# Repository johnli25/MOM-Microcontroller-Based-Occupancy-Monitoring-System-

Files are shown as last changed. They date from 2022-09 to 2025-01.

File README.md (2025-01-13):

# Microcontroller-based Occupancy Monitoring (MOM)

### *Won ECE Senior Design Runner-Up Award* (Fall 2022)

## Authors and Acknowledgements
ECE 445 FA2022 Team 7:
- Franklin Moy
- Vish Gopal Sekar
- John Li
- TA: Hanyin Shao

## About
The goal of this project is to create a web app to allow users to determine how occupied popular study locations are.

## Repository Structure
- [**boards**](boards)
  - Contains KiCad project files for the hardware schematics and PCB layouts.
- [**code**](code)
  - Contains all software created for the project, including those used for RV processes and production code.
- [**models**](models)
  - Contains all custom symbols, footprints, and 3D models used for the hardware and enclosure design.
- [**notebooks**](notebooks)
  - Contains all individual lab notebooks.
 
## Paper/Report
[https://github.com/johnli25/MOM/blob/4fe8f952a4ed27d478e640dd72d3c75059fbbd7b/MOM%20Paper.pdf
](https://github.com/johnli25/MOM/blob/main/MOM%20Paper.pdf)
## The web app/dashboard


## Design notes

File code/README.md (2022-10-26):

# Arduino Code
This folder contains Arduino code for the ESP32-S3 microcontroller. This includes all code used for testing, verification, and project code.
## Setting up the Arduino IDE
- Install the Arduino IDE [from the Arduino website](https://www.arduino.cc/en/software).
- If the `hardware/espressif/esp32` folder is empty, run the below command:
  - `git submodule update --init --recursive`
- Run `get.exe` in the `hardware/espressif/esp32` folder.
- Plug in the board, open the Arduino IDE, and open the IDE preferences (from the topbar: `File->Preferences`).
- Change the Sketchbook location to this folder.
- Copy and paste the below line to the `Additional boards manager URLs`:
  - `https://arduino.esp8266.com/stable/package_esp8266com_index.json,https://dl.espressif.com/dl/package_esp32_index.json`
- Restart the IDE. You should now be able to communicate with the board.
- NOTE: If the IDE throws an error saying it couldn't get the FQDN, you will need to select the board from the topbar: `Tools->Port`

## MAC Address Filtering
In addition, we have a list of MAC address prefixes (also known as Organizationally Unique Identifiers, or OUIs) that belong to Aruba Networks, the company who manufactures the access points used for UIUC networks, and other devices which we believe are not student devices. We use this list to ignore MAC addresses that are a part of the building and improve accuracy of our readings. To get this list, we used the [https://maclookup.app](https://maclookup.app) database, which is derived from the official IEEE database of OUIs [here](https://standards-oui.ieee.org/oui/oui.csv), and put it in this repo [here](MOM/mac-vendors-export-2022-10-25.csv). The repo's snapshot of the database is up to date as of 2022-10-25. 

The list of OUIs can be scraped using the Python3 script [get_ouis.py](MOM/oui_lists/get_ouis.py). The script is used to find all OUIs of a specified company. The script has an argument of the company to find OUIs for. It is case insensitive as it will force all names to lowercase. An example usage is `python3 get_ouis.py aruba` to search for Aruba in the database. It will then output 2 files, one where it directly lists the OUIs in formatted hexadecimal form (`<COMPANY_NAME>-ouis.txt`), and one where the OUI is converted to unsigned integers (`<COMPANY_NAME>-ouis-uints.txt`).

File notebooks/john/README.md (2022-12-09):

# John's Lab Notebook
## Table of Contents
---
- [2022-09-13: Meeting Notes](README.md#2022-09-13-meeting-notes)
- [2022-09-14: Hardware Components Research](README.md#2022-09-14-Hardware-Components-research)
- [2022-09-16: Meeting with Jack Blevins](README.md#2022-09-14-Meeting-With-Jack-Kilby)
- [2022-09-20: Meeting-With-TA](README.md#2022-09-20-Meeting-With-TA)
- [2022-09-25: Finished-First-Draft-Of-Design-Doc](README.md#2022-09-25-Finished-First-Draft-Of-Design-Doc)
- [2022-10-04: Design-Document-review-and-presentation](README.md#2022-09-25-Design-Document-review-and-presentation)
- [2022-10-07: Finalizing-and-Ordering-Parts](README.md#2022-10-07-Finalizing-and-Ordering-Parts)
- [2022-10-18: More Findings about our Project](README.md#2022-10-18-More-Findings-about-our-Project)
- [2022-10-25: Implementation details + Assigning locker](README.md#2022-10-25-Implementation-details-and-Assigning-locker)
- [2022-11-04: Developing the Front End of the Web App](README.md#2022-11-04-Developing-the-Front-End-of-the-Web App)
- [2022-11-15: Mock Demo](README.md#2022-11-15-Mock-Demo)
- [2022-11-24: Thanksgiving Break](README.md#2022-11-24-Happy-Thanksgiving!)
- [2022-11-28: Finishing project for the final demo](README.md#2022-11-28-Finishing-project-for-the-final-demo!)
- [2022-12-4: Preparing-for-final-presentation](README.md#2022-12-4-Preparing-for-final-presentation)
- [2022-12-6: Final-presentation](README.md#2022-12-4-Final-presentation)

## 2022-09-13: Meeting Notes
Discussed with TA regarding our project proposal and our system and subsystem designs. Some things and suggestions to take note of:
- Add subcomponents for the cloud server for block diagram.
- Label necessary voltages at each power line for block diagram.
- Expand high-level requirement involving power to include 24-hour availability while the board is plugged in.
- Don't bother making your own Wi-Fi module; just buy one since budget is $150.

## 2022-09-14: Hardware Components Research
Since we have a limited $150 budget, all of our purchases will most likely be limited to Amazon, Digikey, and Mouser. Parts we are leaning toward using:

**Control Unit and Radio Scanner Suite**
  - [ESP32-S3-MINI-1](https://www.espressif.com/sites/default/files/documentation/esp32-s3-wroom-2_datasheet_en.pdf)
- This ESP32 is versatile, not super expensive, offers various functionalities, and is used in many IoT projects, both hobbyist and professional.
- Furthermore, this microcontroller has been proven to be compatible with AWS. 
- Currently, we aren't planning on integrating the 5 GHz frequency into the Radio Scanner Suite due to time constraints. The primary issue is that if we were to also scan 5 GHz, we would need to purchase a separate Wi-Fi module and write the drivers for it, which would take too much time and effort to integrate. So we plan on settling for 2.4 GHz frequency for our Wi-Fi module for now
- [USB-to-UART Bridge](http://esp32.net/usb-uart/): We need to make use of this bridge and attach it to our ESP-32. 

**Power Supply**
- LiPo battery: safe, effective, efficient, and cheap. Moreover, the "ease and form factor" of LiPo batteries are a plus.
- [AP2112 Voltage Regulator](https://www.digikey.com/en/products/detail/diodes-incorporated/AP2112M-3-3TRG1/5305555) (3.3V): The ESP32 series of SoCs all use 3.3 volts as their operating voltage. Since all USB types generally operating at or above 5 volts, we need to drop the voltage down. 3.3 V is a very common voltage for these sort of scenarios
- [MCP73831T Battery Charge Controller](https://www.digikey.com/en/products/detail/microchip-technology/MCP73831T-2DCI-OT/1979804): mainly used to prevent overcharging

## 2022-09-16: Meeting With Jack Blevins
We met with Jack Blevins, a UIUC alum whom has earned one of the first EECS degrees
back in 1970 and has a 50+-year track record spanning all kinds of
projects in industry (recommended to use by Professor Lumetta), and will essentially serve as another, "informal" mentor for our 445 project. Our team gave an overview of our project and followed up with some questions and comments from Jack:

- Jack essentially solidified our design decision from earlier and agreed that trying to implement and incorporate 5 GHz frequency into our Wi-Fi module would be too impractical. 
- For the Web programming side of things, we discussed which applications, languages, databases, etc. we were going to utilize. Since we established that we would be using AWS for our server side of things, we were leaning toward programming in Python and using a NoSQL Amazon database like DynamoDB. We were also open to using SQL or MongoDB from our discussions.
- Exchanged contact information so we can contact Jack whenever if we had any technical queries regarding our project.

## 2022-09-20: Meeting-With-TA

TA also sent back feedback for our project proposal. Some suggestions + improvements for our it are:

- Add range (+/- 1 minute) to occupancy updating time
- Update visual aid to add a few more explicit labels ("Occupancy data", etc.)
- Change "AWS IoT" in block diagram to "AWS server"
- More comments can be found on project proposal document that TA sent back to us 

We also discussed design document details. For example, creating a system/subsystem requirement | verification table. 

## 2022-09-25: Finished-First-Draft-Of-Design-Doc

- Finished first draft of Design Doc
- Main work we did was circuit schematics and requirements | verifications table for all the system & subsystem requirements

## 2022-10-04: Design-Document-review-and-presentation

- Prior to the Design document review on Monday (10/3/2022), our team made a couple revisions to some of the requirements and verifications, a block diagram, and the visual aid
- Design document presentation on Tuesday (10/4/2022) went well! Lots of great and constructive feedback from TAs, Professor Fliflet, and student peer reviews
- Judging from the feedback, the biggest functionality/implementation challenge we will most likely face is accurately estimating the Wi-Fi and Bluetooth signal strength/RSSI values while accurately pruning out "extra" or multiple signals and connected devices belonging to a single person.

## 2022-10-07: Finalizing-and-Ordering-Parts

- Our team finished finalizing and ordering all the necessary components for our project. Now we are just waiting for everything to arrive.

## 2022-10-18: More Findings about our Project 

- Our team finished finalizing and ordering all the necessary components for our project (PCB, etc.). Now we are just waiting for everything to arrive.

## 2022-10-25: Implementation details and Assigning locker

- We started writing the hardware arduino code for our project (Franklin started this) and cloud/AWS side of our project (Vish and I started looking and writing implementations for this)
- We also got a locker assigned to us, but it currently does not work.

## 2022-11-04: Developing-the-Front-End-of-the-Web-App

- The past couple works, I've been in charge of developing the front end side of the web app. 
- I used the Flask Python module to both design the front end and set up the pertinent connections and endpoints to our backend DynamoDB.
- I followed a Bootstrap + Jinja template for our front end design. The advantages for these web templates are 1) relatively simple learning curve with ample guides online 2) reactive/responsive 3) Provides a variety of designs, colors, graphs, charts, etc.
- The front end design is written in several HTML files so far: 'index.html' and 'pie-siebel.html'

## 2022-11-15: Mock-Demo
- Our group just performed a mock demo, and it went pretty well in my opinion. TAs said the demo went smoothly and we covered many of the requirements and verifications. We also received some very constructive feedback on what we need to address.
- Overall as a group, we need to run more tests on probing the number of devices/people in a closed room. Afterward, we will, together as a group, add more functionalities to ensure our occupancy probing and identifying algorithms and microcontroller sensor data collections are more smooth and consistent in both accuracy and latency
- On the web app side, I have to slightly update 1) the DynamoDB database structure/organizationd and 2) web app functionality in order to pull the most recent data from each room since we made a slight modification/optimization in that regard.
- This is optional but highly recommend. Change the front end design so there's one "home page" which lists all the rooms available on the web app. Then you can "click" on each room in order to navigate to that room and its occupancy metrics. 
- Also, if I have more time, prettify the web app by adding some more reactive widgets/features and colors. This part shouldn't be too hard

## 2022-11-24: Happy-Thanksgiving!
- Grind the points mentioned above and the rest of the MOM project over Thanksgiving break. Halfway-mostly done with the listed points in the entry above. Be ready for the real demo
- Happy Thanksgiving!

## 2022-11-28: Finishing-project-for-the-final-demo
- Finished all the technical/implementation aspects of the project --> ready to demo
- Web application is up, running, and deployed properly, DynamoDB is finished and presents and organizes data in a clean manner, and MOM device successfully reads WiFi signals and uploads to the AWS cloud successfully.
- Prep for demo by reviewing what Franklin, Vish, and I will be presenting which aspects of the project

## 2022-11-29: Demo
- Demo went great! TAs, peer reviewers, and professor liked our project!

## 2022-12-4: Preparing-for-final-presentation
- Prepared slides presentation and what Franklin, Vish, and I will be saying at the presentation
- Try on suits
- Prepared for our final presentation by doing mock presentation 
- also created a video the other day demonstrating our project/MOM device in action

## 2022-12-6: Final-presentation
- Final presentation went great!
- Some intriguing questions by the peer reviewers-if we had the time, their questions/suggestion are 100% worth considering!
- Done with project! Had a lot of fun working on it with my team. Lots of onerous, hard work and very stressful at times throughout the semester, but we got through it!

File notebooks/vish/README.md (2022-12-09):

# Vish's Lab Notebook

## Table of Contents

- [9/13/22: First Meeting with TA](README.md#9/13/22:-First-Meeting-with-TA)
- [9/16/22: Meeting with Jack Blevins](README.md#9/16/22:-Meeting-with-Jack-Blevins)
- [9/17/22: Identifying signals from only phones](README.md#9/17/22:-Identifying-signals-from-only-phones)
- [9/20/22: Second Meeting with TA](README.md#9/20/22:-Second-Meeting-with-TA)
- [9/26/22: Design Document Draft Review with TA and Professor](README.md#9/26/22:-Design-Document-Draft-Review-with-TA-and-Professor)
- [10/4/22: Design Document Presentation](README.md#10/4/22:-Design-Document-Presentation)
- [10/16/22: Development Board Testing](README.md#10/16/22:-Development-Board-Testing)
- [10/24/22: Parts and waiting on PCB](README.md#10/24/22:-Parts-and-waiting-on-PCB)
- [10/31/22: AWS pipeline](README.md#10/31/22:-AWS-pipeline)
- [11/5/22: IoT rule and DynamoDB](README.md#11/5/22:-IoT-rule-and-DynamoDB)
- [11/10/22: Flask Web App](README.md#11/10/22:-Flask-Web-App)
- [11/16/22: Elastic Beanstalk](README.md#11/16/22:-Elastic-Beanstalk)
- [11/27/22: Future Work and Improvements](README.md#11/27/22:-Future-Work-and-Improvements)
- [12/2/22: Post Demo and Preparations for Final Presentation](README.md#12/2/22:-Post-Demo-and-Preparations-for-Final-Presentation)

## 9/13/22: First Meeting with TA
In our first meeting with our TA, we made some introductions and gave her our pitch for the project proposal. Our TA said she did a similar project during her time as an undergraduate in ECE 445, but they used a very different approach with ultrasonic sensors instead. She gave us some advice on our project such as just purchasing a Wi-Fi module instead of trying to build one ourselves.

## 9/16/22: Meeting with Jack Blevins
Jack is an alum from the ECE Department and took some particular interest into our project as he thought it was very interesting. We met with him and gave our pitch for the project as well. He was definitely very invested in our project and gave some thoughtful feedback. He gave us an interesting scenario where the microcontrollers would be placed in neighboring rooms. He told us to find a work-around to account for the fact that the signals from one room could be actually reaching the microcontroller in the other room and vice-versa. This would give an inaccurate count of the number of people in the room as the signals would be counted twice.

## 9/17/22: Identifying signals from only phones
We were initially planning to capture signals from all devices emitting Bluetooth and Wi-Fi signals. However, I thought a more accurate count of the number of people in a room might be just identifying the signals from mobile phones instead. Since most people carry only one phone this would be a lot more accurate. I found a recent [paper](https://cseweb.ucsd.edu/~schulman/docs/oakland22-bletracking.pdf) on this topic where researchers talk about identifying whether the device is a mobile phone from the Bluetooth signal that it is emitting. Here is an [article](https://threatpost.com/bluetooth-signals-track-smartphones/179937/) summarizing this as well. Phones transmit a signal called Bluetooth beacons with an average rate of 500 beacons per minute. If our microcontrollers can somehow identify and isolate the signals that are giving about 500 beacons per minute, then we would be able to identify that the device is a phone. This method, however, might come with its own ethical considerations as it is actively trying to fingerprint and track the device as a phone.

## 9/20/22: Second Meeting with TA
The TA gave her feedback on our project proposal and things to look into for our upcoming design document submission. She told us to update our block diagram as some of the lines connecting to the cloud were confusing, since that's mostly used to indicate physical things. She also mentioned to update our visual aid with more specific labels.

## 9/26/22: Design Document Draft Review with TA and Professor
The Professor gave us some very helpful advice on revising our design doc. Some of the comments he gave:
- Be more specific with the RV table. Should be more low-level as well.
- Don't have random numbers in the requirements. There should be a clear reasoning behind the figures that we are coming up with. 

## 10/4/22: Design Document Presentation
We had our design document presentation yesterday and although we did pretty well, there were a few things that the professor and other peer reviewers brought up. In order to get within our 85% estimation for accuracy that we had in our high-level requirement, we are going to have to calibrate our RSSI value when we start prototyping with our MOM board. This value boundary may change depending on the size of the room/sector where we are testing as well, so we would have to do multiple iterations of it to find out what works to meet our accuracy requirement. During our meeting today there was also a good discussion we had about placement of the devices in a room. For example, what if someone on a floor above the room placed their phone on the ground, while the MOM board was attached on the ceiling of the room below. Arguably, the RSSI value from that device would be higher due to its proximity. Another case might be when a phone is charging from a wall outlet from a shared wall with the room where the MOM board is affixed to. Once again, the MOM board might be picking up signals from that phone, thinking it's also a part of the room. There's a lot of nuances like these cases that we have to do trial-and-error experiments to find an optimal RSSI value to calibrate our MOM boards to looks out for.

## 10/16/22: Development Board Testing
After we received our ESP32 Development Board we started working on figuring out how to pick up probe requests. One of the issues that we found while running our tests was that Apple devices were randomizing their MAC addresses. While all Apple devices did this on default, it was also possible to randomize the hardware addresses for devices running Windows. This would be a problem for our MOM device design, because it would count a probe request coming from a different MAC address every time as a different device, when in fact it might just be the same device sending probe requests with a randomized hardware address every time.

## 10/24/22: Parts and waiting on PCB
We finished ordering all our parts, however, we are still just waiting on our PCB to be delivered. Meanwhile, we are continuing test on the Development Board.

## 10/31/22: AWS pipeline
This week, I spent the bulk of my time refining the AWS Cloud pipeline and how that is going to fit in with the overall scope of the project. AWS has a service called IoT Core that lets you connect billions of IoT devices and route trillions of messages to AWS services without managing infrastructure. When these IoT devices publish messages, they are transmitted and received using the MQTT protocol which minimizes the code footprint on the device and reduces network bandwidth requirements. AWS IoT core is then able to process these messages, communicate with other IoT devices and interact with other AWS services as well. So far, I have gotten the ESP-32 to send MQTT messages to the AWS IoT Core and then it displays it there.

## 11/5/22: IoT rule and DynamoDB
After the MQTT data is saved in the IoT Core we need to save that data in a database, so we can pull it to the web app later. For the database to save to I chose DynamoDB because it is a fully managed, serverless, key-value NoSQL database designed to run high-performance applications at any scale. After messages are received to IoT Core from the ESP-32 using the MQTT protocol, data can be saved to DynamoDB. This can be achieved using the IoT Act Rule. It gives devices the ability to interact with other AWS micro services. Rules are analyzed and actions are performed based on the MQTT topic stream such as writing data received from a device to an Amazon DynamoDB database. 

## 11/10/22: Flask Web App
Now that all the data is saved in DynamoDB, the Flask Web app needs to pull this and display it on the application. I had some trouble with getting the access keys from AWS IAM initially, but after setting up the certificates correctly the Flask Web app was able to pull from my AWS account.

## 11/16/22: Elastic Beanstalk
Since our web application should be accessible from any device, we need a place to host it from that can be accessible easily. Elastic Beanstalk seemed like a good option because it automatically handles the deployment details of capacity provisioning, load balancing, automatic scaling, and web application health monitoring. When trying to initially host it there, we ran into some trouble of getting the dependencies to work in the virtual environment. However, after including a requirements.txt file and writing an appropriate config file, the deployment was successful.

## 11/27/22: Future Work and Improvements
Contrary to our initial inception of the project where we wanted to use both Bluetooth and Wi-Fi signals for occupancy monitoring, we could only implement it with Wi-Fi signals in the end. Implementing occupancy monitoring using Bluetooth proved to be a lot harder than what we expected. However, in the future given more time to work on the project we plan on using a weighted average between cumulative Bluetooth and Wi-Fi traffic to better capture how busy a specific room is. 

Another future improvement to our project could be to include a graph of the most popular times when a room is busy and usually open. This graph would go right below our occupancy pie chart on our web application. The graph would forecast when a room is most available based on historical occupancy data that we would have collected and stored in our database. Using this approach, we could get a rough estimate of the number of people for a given future time. To forecast future occupancy, we could also use more sophisticated models such as an LSTM (Long Short-Term Memory) model which is a type of recurrent neural network that has vast applications when given time series data as inputs. Here is an [article](https://machinelearningmastery.com/how-to-develop-lstm-models-for-time-series-forecasting/) summarizing this well. It can predict pretty accurately when given proper data points and trained appropriately.

## 12/2/22: Post Demo and Preparations for Final Presentation
Our demo went great earlier this week, and our MOM device was 100% accurate in estimating the number of occupants in the senior design lab when we were demonstrating it. We got great feedback from the professor and TAs. As we get near the end of the semester, we need to finish our last two major assignments: Final Presentation and Final Report. We each went over what we will be presenting and rehearsed our sections with a mock presentation, so it would be smooth during the actual one. Also started working on the Final Report since it is due Wednesday next week.

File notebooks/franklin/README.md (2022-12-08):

# Franklin's Lab Notebook
## Table of Contents
- [2022-09-13: Post-Meeting Notes](README.md#2022-09-13-post-meeting-notes)
- [2022-09-14: Parts Research](README.md#2022-09-14-parts-research)
- [2022-09-14: Quick note about our traffic monitoring method](README.md#2022-09-14-quick-note-about-our-traffic-monitoring-method)
- [2022-09-15: AWS Research](README.md#2022-09-15-aws-research)
- [2022-09-24: Full Bill of Materials for MOM Node Prototype 1](README.md#2022-09-24-full-bill-of-materials-for-mom-node-prototype-1)
- [2022-10-02: Calculations and Design Approaches for the Schematic](README.md#2022-10-02-calculations-and-design-approaches-for-the-schematic)
- [2022-10-11: Concerns that arose while doing early testing](README.md#2022-10-11-concerns-that-arose-while-doing-early-testing)
- [2022-10-21: Thinking about implementation](README.md#2022-10-21-thinking-about-implementation)
- [2022-10-26: Experimenting with Probe Requests](README.md#2022-10-26-experimenting-with-probe-requests)
- [2022-11-04: Integrating AWS IoT](README.md#2022-11-04-integrating-aws-iot)
- [2022-11-11: Device Enclosure Preparation with Machine Shop](README.md#2022-11-11-device-enclosure-preparation-with-machine-shop)
- [2022-11-17: Tinkering with the Occupancy Estimation Algorithm](README.md#2022-11-17-tinkering-with-the-occupancy-estimation-algorithm)
- [2022-11-25: Fall Break](README.md#2022-11-25-fall-break)
- [2022-12-02: The Occupancy Contribution/Probability Model](README.md#2022-12-02-the-occupancy-contributionprobability-model)

## 2022-09-13: Post-Meeting Notes 
We just talked with our mentor TA about our initial block diagram, high-level and subsystem requirements, and about some of the parts that we are planning on using for the project. She had some great suggestions for us that we think would benefit our project, especially since she had a very similar project when she took the course. \
Here's the list of suggestions that she mentioned:
- Add the subcomponents for the cloud server in the block diagram.
- Put required voltages at each power line in the block diagram.
- Expand the high-level requirement involving power to include 24-hour availability while the board is plugged in.
- Don't bother making your own Wi-Fi module; just buy one since the budget is $150.

## 2022-09-14: Hardware Parts Research
Now that we kind of have our project idea fleshed out, we need to create an initial list of parts to create our prototype. All research will be done with the fact that the budget can only be used on Amazon, Digi-Key, and Mouser. Below is a list of all parts and components, sorted into subsystems, I have researched that should be purchased from the aforementioned sites, along with my thought process behind picking those parts.
- **Control Unit and Radio Scanner Suite**
  - [ESP32-S3-MINI-1](https://www.espressif.com/sites/default/files/documentation/esp32-s3-mini-1_mini-1u_datasheet_en.pdf)
    - It's no question that the ESP32 family has a good track record with IoT projects. It's very inexpensive and it has a decently-sized community around it to provide support and answers should someone need it.
    - It's also approved and supported by AWS, which is a huge plus should we need help in the programming side of the project.
    - To make this easier for us to quickly build the prototype, we need an ESP32 SoC that has an integrated Bluetooth module as well as a Wi-Fi module to quickly integrate the ***Radio Scanner Suite***. This means we need to get an ESP32 with antennas.
    - As of right now, we aren't planning on integrating the 5 GHz frequency into the ***Radio Scanner Suite*** due to time constraints. The main issue is that if we were to also scan 5 GHz, we would need to purchase a separate Wi-Fi module and write the drivers for it, which would take too much time to integrate.
      - However, the ESP32 that we are getting has native USB support, so if we have the time to integrate the device drivers for the 5 GHz band, we would be able to do so.
      - On the bright side, Espressif is currently developing the ESP32-C5, which will have dual-band and Bluetooth LE capability. This would be the easiest upgrade to scan all Wi-Fi and Bluetooth frequencies, but the release date for this SoC is not currently known (as of 2022-09-14).
  - ~~[USB-to-UART Bridge](http://esp32.net/usb-uart/)~~
    - ~~We need a USB-to-UART bridge IC to actually program our ESP32. The link goes to a web page with a list of USB-to-UART ICs used in other ESP32 development boards, so we know picking one of those should work.~~
    - ~~We are also planning on powering the board through USB when it is plugged in.~~
    - The USB-to-UART Bridge is not necessary for the ESP32-S3 because it has native USB CDC and JTAG support.
      - I go over this in more detail in the notebook entry [2022-09-24: Full Bill of Materials for MOM Node Prototype 1](README.md#2022-09-24-full-bill-of-materials-for-mom-node-prototype-1).
- **Power Supply**
  - LiPo battery
    - 18650 batteries are probably the better choice over choosing a LiPo pack when it comes to the price-to-capacity ratio. However, the ease and form factor of LiPo batteries are more suitable for our design since it's easier to tuck and keep hidden away.
  - [AP2112 Voltage Regulator](https://www.digikey.com/en/products/detail/diodes-incorporated/AP2112M-3-3TRG1/5305555) (3.3V)
    - The ESP32 series of SoCs all use 3.3 volts as their operating voltage. Since all USB types generally operating at or above 5 volts, we need to drop the voltage down. The AP2112 is a tried and true voltage regulator for 3.3 volts, so we'll use it in our design, too.
  - [MCP73831T Battery Charge Controller](https://www.digikey.com/en/products/detail/microchip-technology/MCP73831T-2DCI-OT/1979804)
    - It's very important to keep the battery from overcharging. This battery charge controller appears to be very popular with other boards that are based on ESP32.

## 2022-09-14: Quick note about our traffic monitoring method
So when our team initially talked about this idea, we were certain that we would need to purchase a separate Wi-Fi module to scan both bands of the 802.11 spectrum (2.4 GHz and 5 GHz). However, after a bit of research, and because of a hardware limitation of the ESP32 platform (as of 2022-09-14), we found that only scanning the 2.4 GHz frequency may be sufficient. This is because most Wi-Fi devices send probe requests after a certain event or a certain amount of time, which is dependent on the operating system used by the probing device. These probe requests are sent on both the 2.4 GHz and 5 GHz bands, since not all Wi-Fi networks utilize the 5 GHz band. 

The discovery phase of a Wi-Fi connection can be broken down to the following steps:
1. Wi-Fi client sends a (periodic) probe request to its general viscinity.
2. All Wi-Fi access points (APs) that have read the probe request frame generate and send a probe response to the client (unless the AP is configured otherwise).
3. Wi-Fi client received the probe response from the responding APs to generate the list of available Wi-Fi connections.  
  
Here are some good references to take a look at to learn more:
- [What are Passive and Active Scanning? - Wi-Fi Alliance](https://www.wi-fi.org/knowledge-center/faq/what-are-passive-and-active-scanning)
- [802.11 MAC Series – Basics of MAC Architecture – Part 3 of 3 - CWNP](https://www.cwnp.com/802.11-mac-series-ndash-basics-mac-architecture-ndash-part-3/)
- [Oliveira et al. 2019](https://ieeexplore.ieee.org/stamp/stamp.jsp?arnumber=8747391)

## 2022-09-15: AWS Research
Here's an official AWS web page about how to use AWS for the connected home. This diagram outlines our potential flow with respect to how each device in our fleet will interact with AWS. [Link to diagram here](https://aws.amazon.com/iot/solutions/connected-home/).

## 2022-09-24: Full Bill of Materials for MOM Node Prototype 1
For me, this entire week was spent on finalizing the bill of materials for the first prototype of a MOM node. This list goes in-depth on all major ICs, receptacles, and connectors needed for each MOM node.
- [ESP32-S3-MINI-1-N8 SoC](https://www.digikey.com/en/products/detail/espressif-systems/ESP32-S3-MINI-1-N8/15295890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)
  - ESP32 is a powerful and popular family of SoCs that have microcontrollers, GPIO connectivity, and integrated Wi-Fi and Bluetooth transceivers. We picked the ESP32-S3 specifically because it does not require the use of a separate USB-to-UART bridge to communicate with it from a computer. This is because it contains a USB On-The-Go chip that also supports USB CDC and JTAG. [You can read more about it here](https://docs.espressif.com/projects/esp-idf/en/latest/esp32s3/get-started/establish-serial-connection.html).  
- [Molex USB 2.0 Type-C Receptacle](https://www.digikey.com/en/products/detail/molex/2137160001/13662558)
  - We plan on using USB for flashing software and for the power supply. Thus, we need a USB receptacle for the board.
- [AP2112 (3.3V) Linear Voltage Regulator](https://www.digikey.com/en/products/detail/diodes-incorporated/AP2112M-3-3TRG1/5305555)
  - The ESP32 has a normal operating voltage of 3.3V, and since both LiPo batteries and USB power supply higher voltages, we need to step it down using a voltage regulator. 
- [MCP73831-2ACI Battery Charge Controller](https://www.digikey.com/en/products/detail/microchip-technology/MCP73831T-2ACI-MC/7065590)
  - To ensure proper safety and health of the LiPo backup battery, we will use a battery charge controller. This battery charge controller is popular with other ESP32-based boards.
- [LC709204 Battery Fuel Gauge](https://www.digikey.com/en/products/detail/microchip-technology/MCP73831T-2ACI-MC/7065590)
  - We thought that it would be nice to receive a notification if a node is running on battery power so that we would know if a node's wall power supply needs to be checked out. This battery fuel gauge IC is easy to use and connects directly using I2C.
- [3.7V Li-Po Battery (JST-PH connector)](https://www.digikey.com/en/products/filter/batteries-rechargeable-secondary/91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)
  - This will act as a battery backup should a node's wall power be disconnected for whatever reason.
- [2-pin JST-PH Header](https://www.digikey.com/en/products/detail/jst-sales-america-inc/S2B-PH-K-S-LF-SN/926626)
  - This is a connector for the LiPo battery.
- [DMG3415U MOSFET](https://www.digikey.com/en/products/detail/diodes-incorporated/DMG3415UFY4Q-7/5970445)
  - This is the Diode-OR circuit that will decide whether the wall charger or the battery will power the node.  
- [NRVB540MFS Diode Rectifier](https://www.mouser.com/ProductDetail/onsemi/NRVB540MFST1G?qs=xGcJQ%252BnsJwtnjlj0htu6yg%3D%3D)
  - This diode rectifier is used to keep the incoming power as steady as possible so that other components receive steady power.

## 2022-10-02: Calculations and Design Approaches for the Schematic
- **USB Type-C** 
  - Our decision to use USB for our device stems from the fact that our microcontroller needs to connect to our laptops somehow so that we can program them. Since all modern laptops have USB ports, it would make sense to have a USB interface with the microcontroller so that we can just plug in a USB cable.
  - As we would like to "future-proof" our devices, we decided to go with a USB Type-C receptacle instead of a Micro USB (USB OTG) receptacle.
  - USB is a standard which provides a bus to power devices and transfer data, which makes it a perfect all-in-one solution.
  - MOM devices will never act as USB hosts, as they are simply going to be powered by a USB power supply or will just be programmed by a host computer, so they are (electrically) treated as a sink device on the Configuration Channel (CC) pins.
    - All sink devices will need to have their Configuration Channel pins connected to 5.1K Ohm resistors that are connected to ground.
    - USB Type-C Configuration Channel Requirements  
    - A more in-depth review of the electrical aspects of USB Type-C can be seen in [this document provided by STMicroelectronics](https://www.st.com/resource/en/technical_article/dm00496853-overview-of-usb-type-c-and-power-delivery-technologies-stmicroelectronics.pdf).
- **Battery Charging Circuit**
  - Since we would like to have our backup battery charge while the MOM device is plugged into wall power, we will have a battery charging circuit on the MOM device.
  - This battery charging circuit (part of the Power Supply subsystem) is made up of two ICs: an MCP73831 battery charge controller and a MAX17048G battery fuel gauge.
  - The MCP73831 is a popular battery management controller for Lithium-Polymer batteries. As such, we chose it as our battery charge controller.
    - Because we want to have each MOM device to last for at least one hour while on battery power, we calculated that the minimum battery capacity required to do so is at least 500mAh.
    - For Lithium-Polymer batteries, it is unsafe to charge it at a current that is higher than its capacity divided by one hour. For our battery, this means that we should not charge it using a current higher than 500mA.
    - The MCP73831 datasheet provides a simple formula (seen below) that we can use to set its charge rate by using a programming resistor at its "PROG" pin.
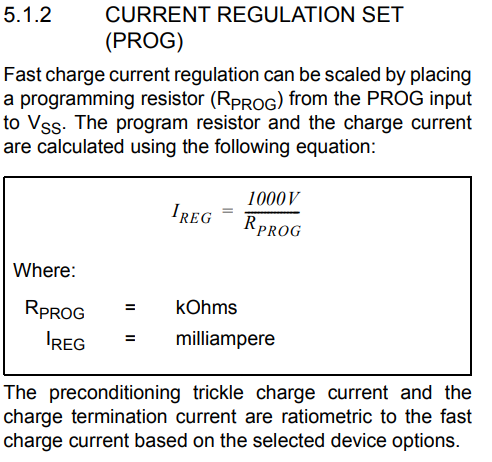
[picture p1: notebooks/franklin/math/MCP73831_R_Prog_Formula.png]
MCP73831 charge rate formula from its datasheet
    - 
    - From this formula, we can see that the resistance of the programming resistor required to set the current to no more than 500mA is ***2K Ohms***.
  - The MAX17048G is a battery fuel gauge that can calculate battery levels and communicate its findings over I2C. We plan on using this to display the battery level of each node so we can determine if there are any issues with the battery backup of that node.
    - Since we are going to just use it as a simple fuel gauge, we decided to use the typical application circuit shown below (which was also from the datasheet).
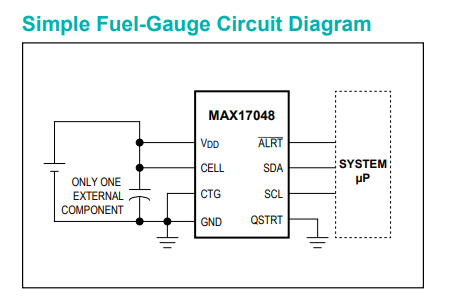
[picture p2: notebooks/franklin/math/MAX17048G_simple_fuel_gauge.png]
Simple MAX17048G fuel gauge circuit
    - 
- **Battery Backup Switchover**
  - After doing some research, I found that the most efficient circuit for a (relatively) seamless battery backup switchover circuit involves a P-channel MOSFET. By having the voltage from USB as the gate, and the voltage from the battery as the source/drain, you can easily decide which power source to draw from.
  - In this setup, when USB is powering the device, the voltage drop between the gate and source (Vgs) will be above the turn-on voltage range, so no power from the battery will go through. When USB is disconnected from the device, Vgs will be within the range of turn-on voltage range, allowing power from the battery to go through.
  - There is a Schottky diode used to protect the USB power line from battery power. A Schottky diode was chosen due to its low turn-on/forward voltage, and the specific model being used was chosen due to its combination of high reverse voltage blocking and low reverse current leakage.
- **Voltage Regulator**
  - The AP2112 is a commonly used voltage regulator in microcontroller platforms that use 3.3 volts, so we picked it because of that. 

## 2022-10-11: Concerns that arose while doing early testing
Our parts came in earlier this week and we were able to pick them up. Among the parts that we ordered is a development board that we plan to use to code our microcontroller program while we wait for PCB orders to be fulfilled. As we started developing, we found out about an issue that would force us into making certain algorithm design decisions. This issue is how a device is able to randomize its Wi-Fi MAC address. For example, every time an iOS device sends a probe request, it will randomize its MAC address for each request. This would make it very difficult to have the true count of devices using just basic MAC address storage/lookup. 

We're thinking that one way of mitigating this would be connecting to IllinoisNet instead of the IllinoisNet_Guest network so that we could truly monitor just IllinoisNet. This would cause each device to just be mapped to a single MAC address since the MAC address cannot be changed during a connection. Since IllinoisNet requires a certificate, we could do something similar to how [someone at UMich connected their ESP32 to their university's network](https://www.youtube.com/watch?v=bABHeMea-P0).

Fortunately, one of the references in our RFA/design document proposes another way of mitigating this. You can read the proposed method in the [research publication on IEEE](https://ieeexplore.ieee.org/stamp/stamp.jsp?tp=&arnumber=8747391).

## 2022-10-21: Thinking about implementation
So while we're waiting for our PCB to come in, we've been developing using the development board that we ordered. So far, we have had a bit of success with the current code that we have. Now, we're trying to look for ways to optimize the counting algorithm and make it as accurate as we can. This involves a bit more testing and some more math. We've also started researching how to implment the IoT Cloud subsystem on AWS and how to connect the development board to it. 

## 2022-10-26: Experimenting with Probe Requests
I spent a couple days this week trying to tune the parameters for Wi-Fi scanning. However, one of the problems that I found while I was experimenting was with respect to the frequency that devices send probe requests while already connected to a network. When a device sends a probe while already connected to a network, it sends significantly fewer probe requests than if it were not connected. 

One of my experiments this week involved finding the time intervals in which different computer operating systems send probe requests while already connected to a network. I put a MOM node next to the devices I was testing and let it collect data over a period of one hour. These devices consisted of my laptop running Windows 10/11, a smartphone running Android, a smartphone running iOS, and one of my roommate's laptops running macOS. My roommate and I were actively using our respective laptops, while both smartphones were left in a locked state.

During this one hour interval, I found that devices running Windows 10/11 send a probe request about every 10 minutes (which can be seen in the screenshots below). On one occasion, our MOM device caught traffic from the Windows device less than 2 minutes after its previous probe request, but this wouldn't have an effect on how we plan on measuring occupancy if this happened in the real world. 

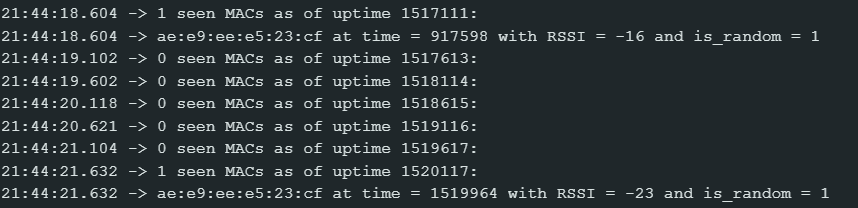
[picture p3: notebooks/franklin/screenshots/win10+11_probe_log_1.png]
Windows 10 Probe Request detection 1

Windows 10 Probe Request detection 2
Windows 10 Probe Request detection 3

We also found that the probe request interval for MacBooks running macOS is also about every 10 minutes. However, we found that iOS rarely sends probe requests when it is locked. This could be a double-edged sword. On one hand, it helps mitigate over-counting people if they have multiple Wi-Fi devices. On the other hand, if a person isn't using their laptop (if they are taking a break from studying, for example) we could be under-counting because the MOM node would not count the actively used smartphone. In the end, I'll still need to figure out if (and how) we can keep the occupancy measurement as close to ground truth as possible.

## 2022-11-04: Integrating AWS IoT
I spent the bulk of this week adding the integration with AWS IoT into the microcontroller codebase. To publish the occupancy data to the database for the web application to use, the microcontroller will use the MQTT protocol to send messages to the AWS IoT Core. The AWS IoT Core can then forward the MQTT message it receives from the MOM device to a database via a forwarding rule. The web application can read from the database to update the occupancy data on the web page. This follows the official AWS IoT Core flow diagram below.

Official AWS IoT flow diagram

Since there is only one Wi-Fi antenna on the ESP32-S3, it cannot be connected to the internet and scan for Wi-FI traffic simultaneously. To overcome this, I programmed the microcontroller to switch between the two modes. Depending on what part of the data collection flow the MOM node is currently on, it will set the Wi-Fi antenna to the corresponding mode. When it is scanning, the antenna is put into promiscuous mode. After a certain amount of time, promiscuous mode is turned off, and it starts to estimate the occupancy based on the scan data. After it does that, it will set the Wi-Fi antenna to station mode and connect to the internet and AWS. Once it publishes the data, it will disconnect from the internet and re-enable promiscuous mode to scan for probe requests again. See the flowchart and an example demo screenshot below.

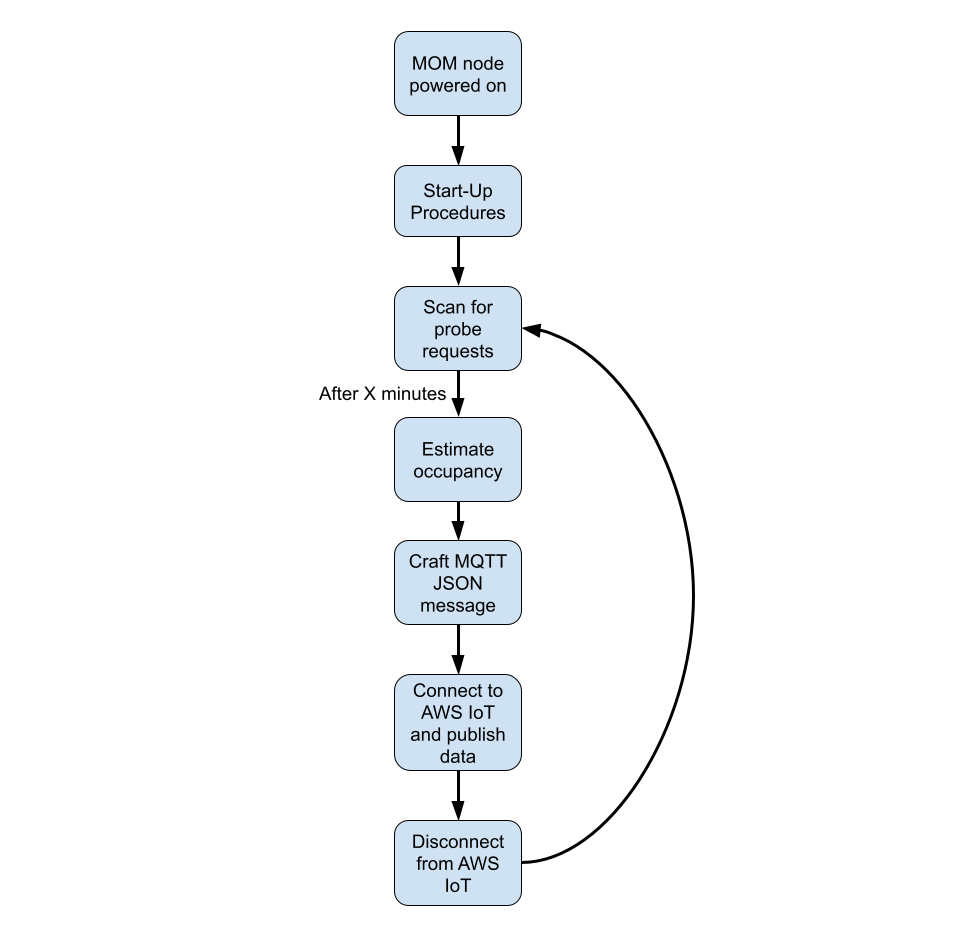
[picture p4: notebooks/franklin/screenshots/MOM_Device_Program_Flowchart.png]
MOM Device Flowchart


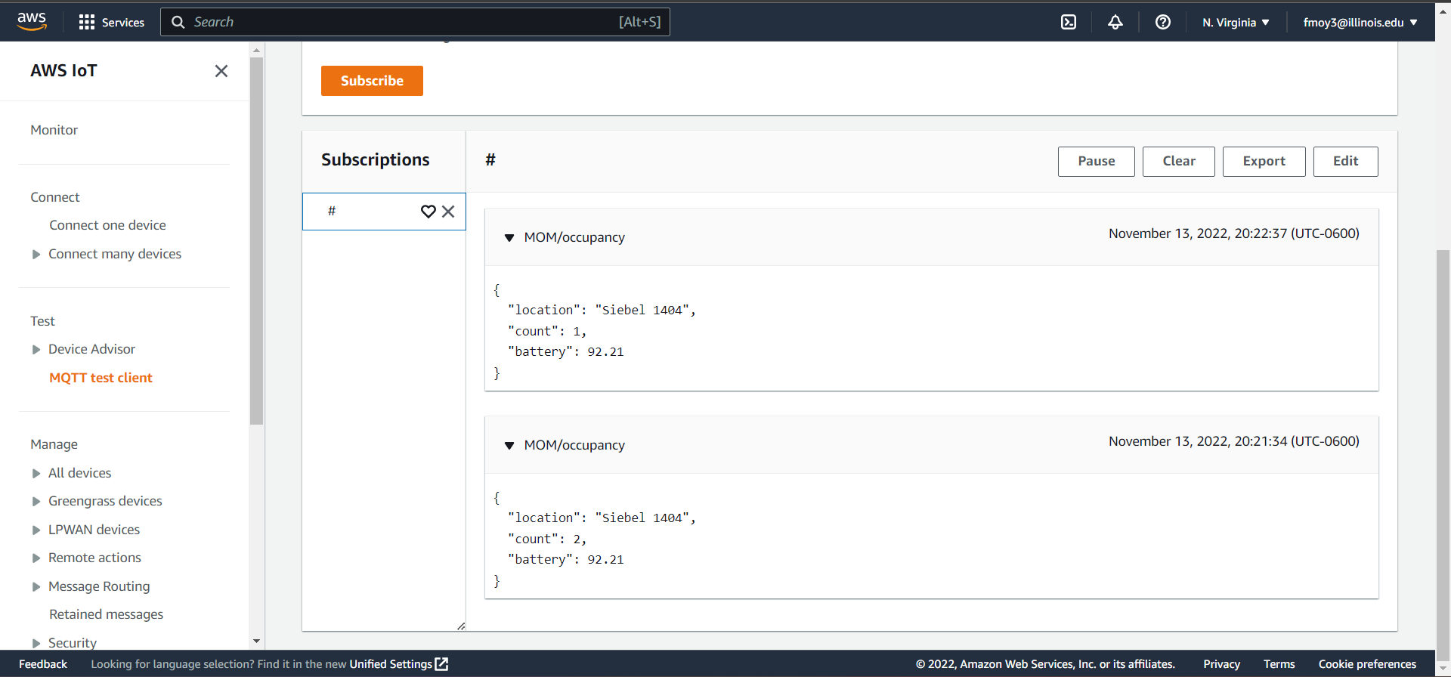
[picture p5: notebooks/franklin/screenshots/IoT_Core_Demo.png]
MOM IoT Core Demo


## 2022-11-11: Device Enclosure Preparation with Machine Shop
I spent this week with more attempts of fine tuning the occupancy estimation algorithm. Unfortunately, I couldn't get too much progress with this, even after reading some more research papers on the topic. The primary issue with referencing most of the research papers on the topic of occupancy detection through probe requests is the fact that the scenarios that apply to the research publications don't apply to the scenario in which we are deploying MOM. I briefly touch on this in [2022-10-26: Experimenting with Probe Requests](README.md#2022-10-26-experimenting-with-probe-requests), but to elaborate, the research publications target scenarios when the devices are not already connected to a network, such as on public transportation or while out and about. 

In these scenarios, client devices send probe requests much more frequently, allowing the researchers to use algorithms to map patterns to estimate occupancy. Since we plan on deploying MOM devices in places such as a public library, the devices will already be connected to a network like IllinoisNet. This makes it harder for us to keep tabs on these devices in real-time since they don't send probe requests often, if at all, while already connected to the internet. I am trying to come up with an algorithm of my own to estimate occupancy in our situation, which I will be continuing work on next week.

Meanwhile, I was also working with Gregg from the Machine Shop this week to build an enclosure for our MOM device. We found a plastic enclosure that suits the size of our PCB and backup battery. A plastic enclosure should not affect any the signal strength parameters that the algorithm uses since plastic is practically invisible to the 2.4GHz waves that we are using. Gregg and the others from the Machine Shop will drill holes in the plastic enclosure so that the MOM board can be mounted to the case. Also, a hole will be made on one side of the enclosure for the USB-C port on the board, allowing for easy connection with a USB-C cable to program and power the board while it is in the case.

## 2022-11-17: Tinkering with the Occupancy Estimation Algorithm
At this point, the physical MOM device is ready and is packaged in an enclosure. I've noticed that the enclosure slightly interferes with the RSSI tolerance ranges that the algorithm uses, but it shouldn't have too much of an impact. However, as I was adjusting these tolerances, I found that the current algorithm does not do a good job of trying to mitigate things such as counting people who are simply passing by and the MAC address randomization used for probing by mobile devices, both of which would cause overcounting. 

Another concern is that not every Windows machine will send periodic probe requests while already connected to the internet. For example, my Windows laptop is equipped with an Intel Wi-Fi controller. When I was testing an earlier version of the algorithm a couple of weeks ago, I found that my laptop sent probe requests with a period of about 10 minutes. However, one of my teammate's laptops has a Wi-Fi controller manufactured by a different company. As these Wi-Fi controllers are made by different companies, the software drivers for them are also developed differently. As such, they may not behave exactly the same, and this is what I saw with my teammate's laptop, as it didn't probe at all when already connected to the internet during a 30-minute testing period.

Because of this and the possible overcounting, I decided to rethink what exactly occupancy would mean in our project, since we won't be able to reliably map the occupancy to just the number of MAC addresses we see from probe requests at a given point in time. For now, the best metric/model I could think of involves traffic flow and how busy the area seems. As someone walks through a building, their smartphone's connection to the access point it was previously connected to becomes weaker and weaker. It is at this point when the smartphone sends a probe request to try and connect to an access point with a stronger signal. If we can capture this traffic flow and then try to map it to the number of people in an area, then we can estimate occupancy that way. We also need to consider signal strength relative to the MOM device to try to see if the traffic is within the room or just passing by.

## 2022-11-25: Fall Break
This week was Fall Break, and since I was more or less done with building the physical MOM device and developing the microcontroller code for it, I was only performing the final verifications and recording our results. All of the requirements for the subsystems I was in charge of have been verified, and so was the high-level requirement of the device running for at least one hour while on battery power. However, because of the scarcity of sent probe requests by devices already connected to the internet, the high-level requirement of estimating sector occupancy with at least 80% accuracy is becoming increasingly more difficult through just measuring probe requests. If we used a much more intrusive method, this would not be too difficult. However, ethical reasons deter the usage of these intrusive methods.

## 2022-12-02: The Occupancy Contribution/Probability Model
We noticed that after monitoring a space for a long time, the MOM device eventually reads an explosive increase in detected devices when no new people enter the room, which in turn increases the estimated occupancy. To mitigate this, we instead calculate occupancy based off of the probability that the detected device represents an entire person. With this new probability model, we try to take into account factors such as the number of devices per person, the dimensions of the environment where the device is deployed, and extraneous traffic from devices from other areas (such as other floors and other rooms). The probability primarily focuses on the signal strength and timestamps of each captured probe request, where the probability decays over time if the device has not been seen for a while since the previous timestamp. We also tried to implement a way to detect explosive increases in detected devices within a short period of time. While we were able to detect and mitigate these, the algorithm we use would ignore explosive increases if it actually happened. For example, if a class is starting in a classroom, and many students enter the room at the same time, the algorithm currently thinks that mitigation actions are required even though the increase is the ground truth.

In general, the mitigation would not really matter too much for the areas where we would be primarily deploying MOM devices, such as Grainger Library and the ECEB Atrium, since those are large, open spaces with lots of movementand traffic flow. When we tested this algorithm in the Senior Design Lab, we found that it works relatively well. It would be rare to see explosive increases in occupancy in a short period in those spaces. However, the shortcoming of this mitigation approach is losing the accuracy in smaller rooms. Given more time to fine-tune the mitigation algorithm, I believe that we would be able to find an optimal way to identify when mitigation actions should be taken based on these explosive increases.

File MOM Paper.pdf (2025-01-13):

# ECE 445

### Senior Design Laboratory Fall 2022 Final Report

# Microcontroller-based Occupancy Monitoring (MOM)

Team 7: Franklin Moy, Vish Gopal Sekar, John Li TA: Hanyin Shao
12/07/2022

## Abstract

Microcontroller-based Occupancy Monitoring (MOM) is a project which shows the current occupancy of a space to its users. The MOM device monitors Wi-Fi traffic density to estimate the number of people in a space in real-time. This estimation is presented on a web application for the public to use. By using the web application, users can know if a location is likely to have available seats without needing to physically visit the location. Using a custom algorithm with finely-tuned parameters, MOM is able to estimate the number of people in a large, enclosed space with at least 80% accuracy and update the web application every five minutes or less.

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
### 1 Introduction

1
1.1 Problem

1
1.2 Solution

1
1.3

Visual Aid

2
1.4 High-Level Requirements

2
1.5 Subsystem Overview

3
1.5.1 Control Unit

4
1.5.2 Radio Scanner Suite

4
1.5.3 Power Supply

4
1.5.4 IoT Cloud

4

### 2 Design

5
2.1 Control Unit

5
2.1.1 Design Procedure

5
2.1.2 Design Details

5
2.2 Radio Scanner Suite

6
2.2.1 Design Procedure

6
2.2.2 Design Details

7
2.3 Power Supply

7
2.3.1 Design Procedure

7
2.3.2 Design Details

7
2.4 IoT Cloud | 10
2.4.1 Design Procedure | 10
2.4.2 Design Details | 10
2.5 Occupancy Estimation Algorithm | 1
| 1
2.5.1 Design Procedure | 1
| 1
2.5.2 Design Details | 1
| 1

### 3 Design

Verification | 13
3.1 Control Unit | 13
3.2 Radio Scanner Suite | 13
3.3 Power Supply | 13
3.3.1 Battery Charger | 13
3.3.2 Power Source Decision Circuit | 14
3.4 IoT Cloud | 14
3.4.1 MQTT Service | 14
| ii

3.4.2 Web Application | 15
4 Cost and Schedule | 16
4.1 Parts | 16
4.2 Labor | 17
5 Conclusion | 18
5.1 Accomplishments | 18
5.2 Uncertainties | 18
5.3 Ethical Considerations | 18
5.4 Future Work | 19
References | 20
Appendix A: Requirements & Verification Tables | 22
Appendix B: Web Application User Interface | 26
Appendix C: Schematic, PCB, and Final Product | 27
Appendix D: Battery Test Results | 29
Appendix E: Battery Charger Overcharge Test | 30
Appendix F: Monitoring Program Flow | 31

iii

## 1 Introduction

### 1.1 Problem

With the campus returning to normalcy from the pandemic, most, if not all, students have returned to campus for the school year. This means that more and more students will be going to the libraries to study, which also means that the limited space at the libraries will be filled up with the many students who are now back on campus. Even in the semesters during the pandemic, many students have entered libraries such as Grainger to find a place to study, only to leave 5 minutes later because there are no open seats. With the closing of the Undergraduate Library in the Spring 2022 semester, it is likely that this problem will get worse.

Libraries play an essential role in the academic side of the college experience. In a 2015 research survey conducted by Gensler [1], libraries were ranked as the top places for students to study alone and work in a group, with providing quiet space for work ranked as its important resource. However, when there is a lack of study spaces for students, especially during midterm exam periods, this could have a negative impact on students. It could not only reduce the amount of study time available to a student, but it may also reduce motivation to study. As mentioned in an article written by the Daily Bruin, the official student newspaper at the University of California, Los Angeles [2], students have attributed the lack of open study spaces as a cause of unnecessary stress which may affect academic performance.

### 1.2 Solution

Our solution utilizes a fleet of custom devices that will scan for nearby Wi-Fi and Bluetooth network signals in different areas of a building. Since students nowadays will be using phones and/or laptops that emit Wi-Fi signals, scanning for Wi-Fi signals is a good way to estimate the fullness of a building. In an IEEE research article about the effectiveness of using Wi-Fi probe requests to estimate the presence of people [3], the authors found that their proposed method indicated a very strong correlation with the actual number of people present in their environment of study. Our custom devices, which can be deployed in any location near a wall outlet, will be able to scan for these connections. They will then compile occupancy data for their assigned sectors and feed this data into an Internet of Things (IoT) core in the cloud. This IoT core will send information to a cloud database. The database will connect with our web application which students will use to locate open study spaces without aimlessly searching around campus.

It should be mentioned that other occupancy monitoring products exist, such as the Waitz [4] system from the University of California, San Diego. However, those products rely on the use of hardware that are currently experiencing supply chain issues [5], [6]. Our solution will be using microcontrollers and parts which are inexpensive and readily available. Each one of our devices will also have a battery backup, which many existing solutions do not have.

### 1.3 Visual Aid

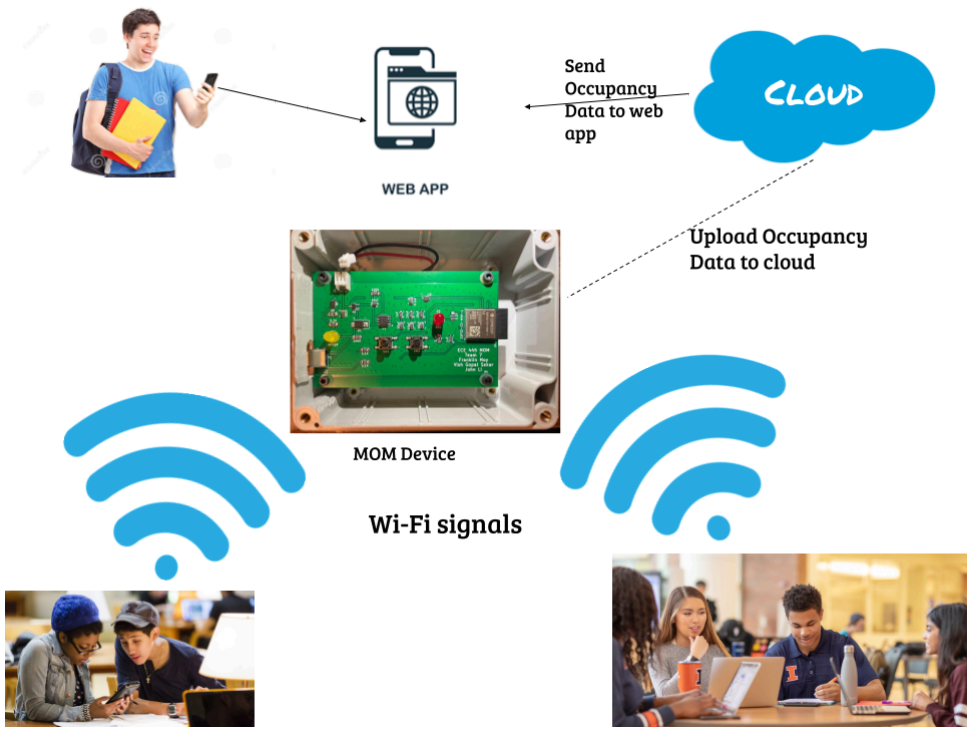
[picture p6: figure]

Figure 1: Interactions between MOM Device, Student Devices, and Web Application

### 1.4 High-Level Requirements

- Estimation Accuracy: For users to have confidence in the presented data, each MOM device must be able to estimate sector occupancy with at least 80% accuracy.
- Battery Life: Each MOM device must be able to run indefinitely while plugged into wall power and for at least one hour when unplugged.
- Frequent Updates: The MOM device must consistently send occupancy data such that the web application shows data no more than 5 minutes old.

### 1.5 Subsystem Overview

There are four subsystems that make up the MOM project. Three of these subsystems make up a physical MOM device: the Power Supply, Radio Scanner Suite, and Control Unit. The fourth subsystem, the IoT Cloud, is a purely software-based subsystem that resides in the cloud. Figure 2 below shows the components of each subsystem and how the subsystems interact with each other. An explanation of each subsystem is provided on the following page.

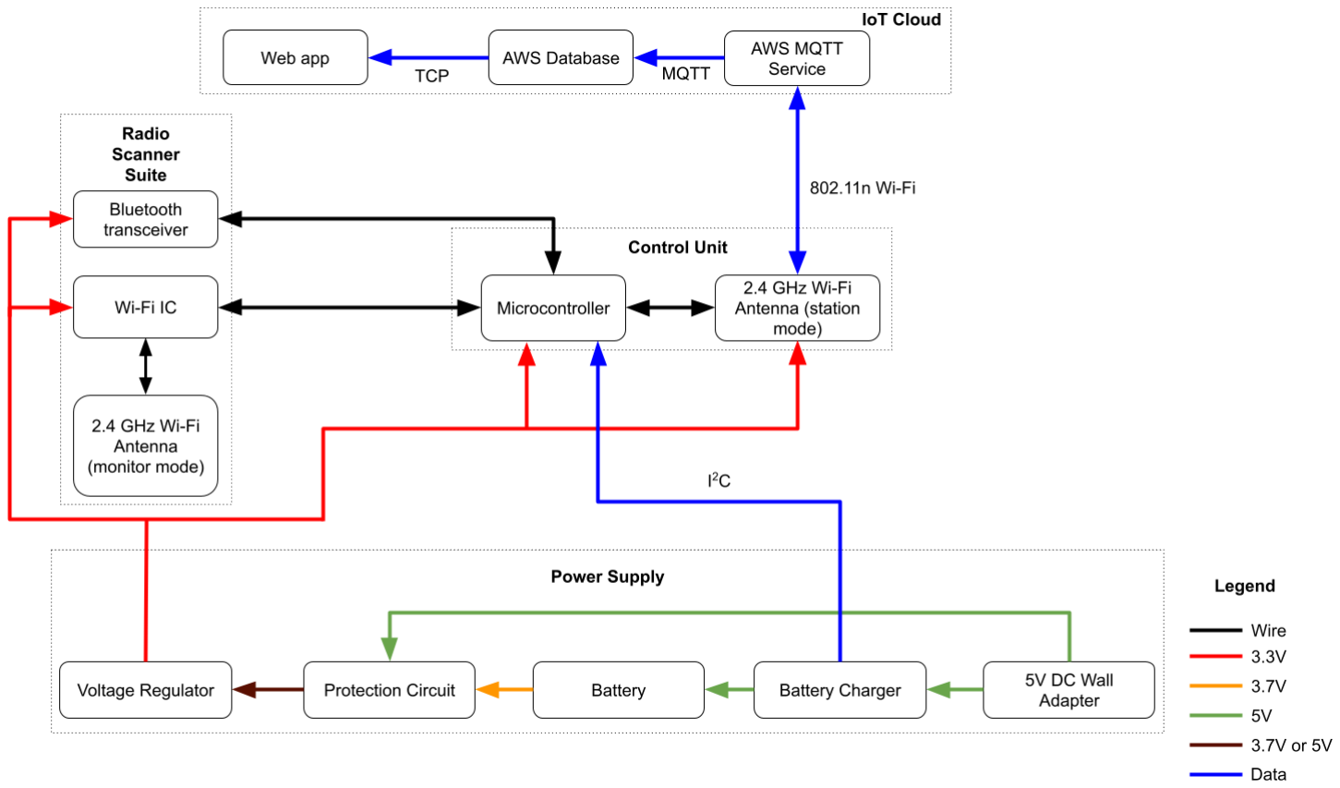
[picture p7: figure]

Figure 2: Block Diagram

### 1.5.1 Control Unit

The Control Unit receives information about Wi-Fi traffic density from the Radio Scanner Suite. It will then compile and process this data to estimate the occupancy of the sector that it is monitoring. Once it finishes processing this data, it will connect to the internet and send the data to the IoT Cloud subsystem.

### 1.5.2 Radio Scanner Suite

The Radio Scanner Suite is the subsystem that scans for Wi-Fi traffic. Since most, if not all, modern personal devices contain Wi-Fi radios that communicate in the 2.4 GHz frequency band, we will be monitoring this Wi-Fi frequency to estimate occupancy. The Radio Scanner Suite consists of the necessary components for monitoring these types of RF transmissions. For each packet of Wi-Fi traffic the Radio Scanner Suite picks up, it will send it to the Control Unit for occupancy data processing.

### 1.5.3 Power Supply

The Power Supply delivers power to the Radio Scanner Suite and Control Unit, allowing them to perform their respective functions. The Power Supply consists of a standard 5V USB DC power supply and a lithium-polymer backup battery. If power from the wall outlet is interrupted, the power supply will be able to instantly switch and draw power from the backup battery.

### 1.5.4 IoT Cloud

The IoT Cloud subsystem is a purely software-based subsystem. This subsystem leverages Amazon Web Services (AWS) for web application hosting, occupancy data retrieval, and database management. It receives occupancy data from all MOM devices, compiles them, and then displays them on the web application for users to see. The web application is available to the public and can be accessed on any device with a web browser.

## 2 Design

### 2.1 Control Unit

### 2.1.1 Design Procedure

The Control Unit of each MOM device only requires a microcontroller to process occupancy data and a Wi-Fi transceiver to send this data to the IoT Cloud. Thus, the design procedure for the Control Unit was to find a suitable System on a Chip (SoC) with both of these features. There are many SoC manufacturers who develop products meeting our requirements, including Nordic Semiconductors and Silicon Labs. However, the products from these manufacturers are not only expensive, but many were, and still are, out of stock. However, one SoC platform stands out from the rest for our project. Espressif's ESP32 family of SoCs are not only widely available, but they are also inexpensive and popular within the Internet of Things industry.

### 2.1.2 Design Details

The ESP32-S3-MINI-1 SoC was selected as the SoC for MOM devices due to its low cost, small form factor, and robust development platform. It consists of a ESP32-S3 microcontroller and a programmable Wi-Fi antenna, which makes integrating the Radio Scanner Suite simple. Additionally, we included an LED which connects to one of the microcontroller's General-Purpose Input/Output (GPIO) pins to indicate when the monitoring program is active.

In order to program the microcontroller, there needs to be an interface to power it and connect it to a development computer. The ESP32-S3-MINI-1 has a native USB interface for this purpose, so connecting the USB GPIO pins to the corresponding pins on a USB connector is enough to create this interface. Two buttons used for restarting and setting the SoC into program mode are also present in the design. The schematic for the Control Unit can be seen in Figure 3 on the following page.

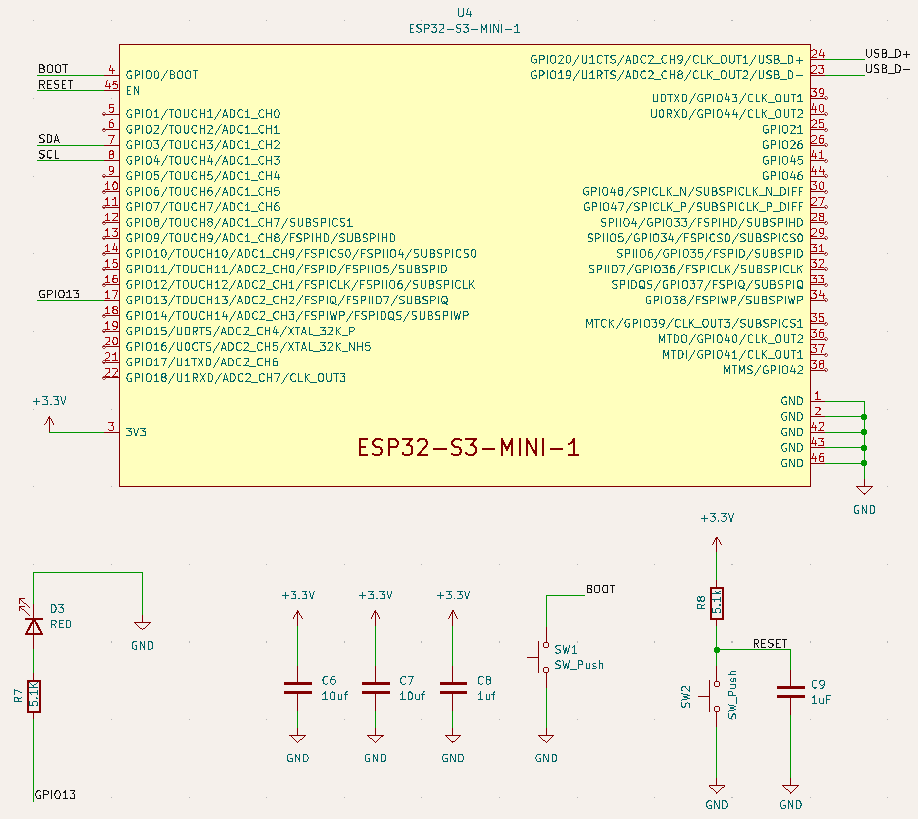
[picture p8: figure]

Figure 3: Schematic of the Control Unit

### 2.2 Radio Scanner Suite

### 2.2.1 Design Procedure

Since it will be monitoring Wi-Fi traffic, the Radio Scanner Suite must have an antenna and Wi-Fi controller capable of operating under Wi-Fi 4, also known as the IEEE 802.11n protocol, or newer. One of the initial designs of a MOM device involved creating the Radio Scanner Suite from scratch, which would involve purchasing and programming a separate companion chip and connecting it to antennas. This would not only be complex and time consuming, but this design later became redundant since the ESP32-S3-MINI-1 already has a Wi-Fi interface with an antenna. Ultimately, the Radio Scanner Suite was implemented using the Wi-Fi interface on the ESP32-S3-MINI-1.

### 2.2.2 Design Details

The Wi-Fi interface in the Radio Scanner Suite is fully controlled by the microcontroller in the Control Unit. Although the Wi-Fi interface can switch between the 11 available channels under the 2.4 GHz frequency band, we decided to only monitor Channel 1. This is because probe requests, the type of traffic we are targeting, are transmitted on every Wi-Fi channel to search for available access points. This ultimately means that it does not matter which channel the Radio Scanner Suite is targeting.

After collecting occupancy data for a set period, the data needs to be transmitted to the IoT Cloud to keep the web application updated. The microcontroller can programmatically switch the Wi-Fi interface between monitor mode for occupancy monitoring and station mode for data transmission. Thus, the microcontroller was programmed to switch to station mode every one or two minutes, send the occupancy data, and switch back to monitor mode when done.

### 2.3 Power Supply

### 2.3.1 Design Procedure

Ideally, MOM devices deployed in a building would be plugged into a wall outlet. Since a USB interface already exists for the purpose of powering and programming the microcontroller, other components on the device can utilize the same bus to draw power. This means that any off-the-shelf USB wall plug and USB-C cable can be used to power a MOM device.

In addition, we wanted each MOM device to have the ability to instantly switch to backup battery power so that each device can still operate in the event of a wall power disruption. While 18650 batteries would be able to deliver the necessary power, lithium-polymer batteries were chosen as the battery type due to the slimmer form factor. To notify us of the state of charge of the backup battery, we selected the MAX17048G as the battery fuel gauge since it requires minimal configuration, is designed specifically for lithium-polymer batteries, and is able to communicate with the Control Unit to report this information. We also thought it would be a good idea to charge the backup battery when the device is powered by the wall outlet.

### 2.3.2 Design Details

The ESP32-S3-MINI-1 SoC, which houses the Control Unit and Radio Scanner Suite, requires a voltage of 3.3 volts for safe operation [7]. To step the input voltage down to 3.3 V, we use an AP2112 low-dropout voltage regulator. It is able to step down both the five-volt input from USB and the average of 3.7 V from the backup battery to 3.3 V.

However, only one power source should be used to power the device at a time. For a MOM device, this means deciding between wall power or battery power. Since we only want the battery to be used when wall power is not available, we use a P-Channel MOSFET in conjunction with a Schottky diode as a decision circuit. As illustrated in Figure 4 on the next page, when wall power is present, the P-Channel MOSFET prevents power from the battery going to the device. When wall power is not present, the P-Channel MOSFET acts as a short, and the battery is used to power the device, with the Schottky diode blocking the battery power from going to the USB line.

Since the device needs to be able to run on battery power for at least one hour, the capacity of the backup battery needs to be at least a certain value. To calculate the minimum battery capacity, we used Equation 1 below. The ESP32-S3-MINI-1 has a current draw of 500 mA [7]. Since we want each device to run for at least one hour, the battery capacity must be at least 500 mAH. During our testing, the MOM device was able to run for about five hours while powered by the battery. The results of the battery life test can be seen in Figure 13 in Appendix D.

Capacity [mAH] = I | (1)
VDD

[mA] * Runtime [ℎours] = 500 [mA] * 1 [ℎour]

To charge the battery while connected to wall power, the USB power line is also connected to a battery charger, which consists of an MCP73831 lithium-polymer battery charge controller. The charging rate of the MCP73831 can be programmed by using a programming resistor, allowing the charging rate to be optimized to the specific battery the controller is charging. Equation 2 shows the formula to calculate the resistance of the programming resistor to optimize the charging rate [8]. Since the backup battery will have a capacity of 500 mAH, this means the regular charge current, or the one-cell charging rate, is 500 mA. From the formula, we can see that the resistance of the programming resistor should be 2 kΩ. The charging rate of the battery charger can be seen in Figure 14 in Appendix D, and the circuit schematic can be seen in Figure 5 on the next page.

R | (2)
prog

[Ω] =

1000 V
I
reg

[A] =

1000 V
0.5 A = 2 kΩ

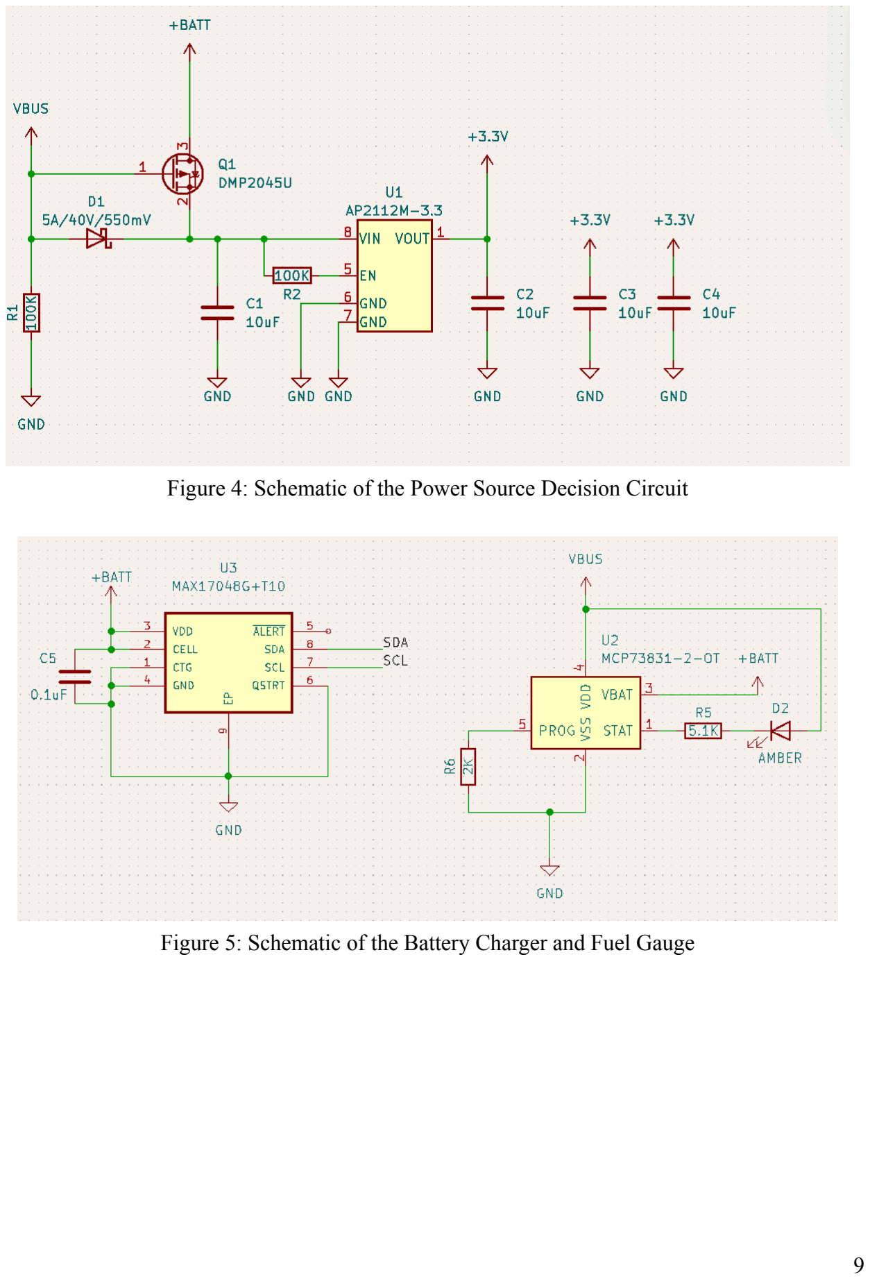
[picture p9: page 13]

Figure 4: Schematic of the Power Source Decision Circuit

Figure 5: Schematic of the Battery Charger and Fuel Gauge

### 2.4 IoT Cloud

### 2.4.1 Design Procedure

The IoT Cloud subsystem consists of the web application itself as well as the infrastructure to host it, store occupancy data, and receive messages from MOM devices. We selected AWS as our cloud provider of choice since it has all of the cloud services we need such as a database, IoT core, and web application hosting platform. AWS also has ways to seamlessly integrate these different services together with minimal setup.

For the web application, we needed a simple full-stack application that was both deployable on AWS and capable of communicating with the AWS database. Today, there are a plethora of publicly available and open-source web development frameworks that are capable of both. However, we needed a framework that was minimal since we wanted our web application to be fast and scalable.

### 2.4.2 Design Details

Since we needed a web development framework that was easy to learn and performant, we chose to develop it under the Python Flask framework. Python Flask is a full-stack micro framework that is easy to develop under and configure. It can be deployed on AWS using AWS Elastic Beanstalk and, just like most other Python frameworks, can utilize the vast collection of Python modules available. One such module is Amazon's official module to interact with AWS, Boto3.

For the underlying AWS infrastructure, we designed a flow that enables data from the MOM device to be sent to the web application for users to see, which can be seen in Figure 6 below. First, each MOM device will use the MQTT protocol to publish occupancy data to the AWS IoT Core. Then, we have the IoT Core receive each message and store them in the occupancy metrics database. From there, whenever a user accesses the web application, the backend of the web application will pull the data from the database and send it to the user interface. The web application user interface can be seen in Appendix B.

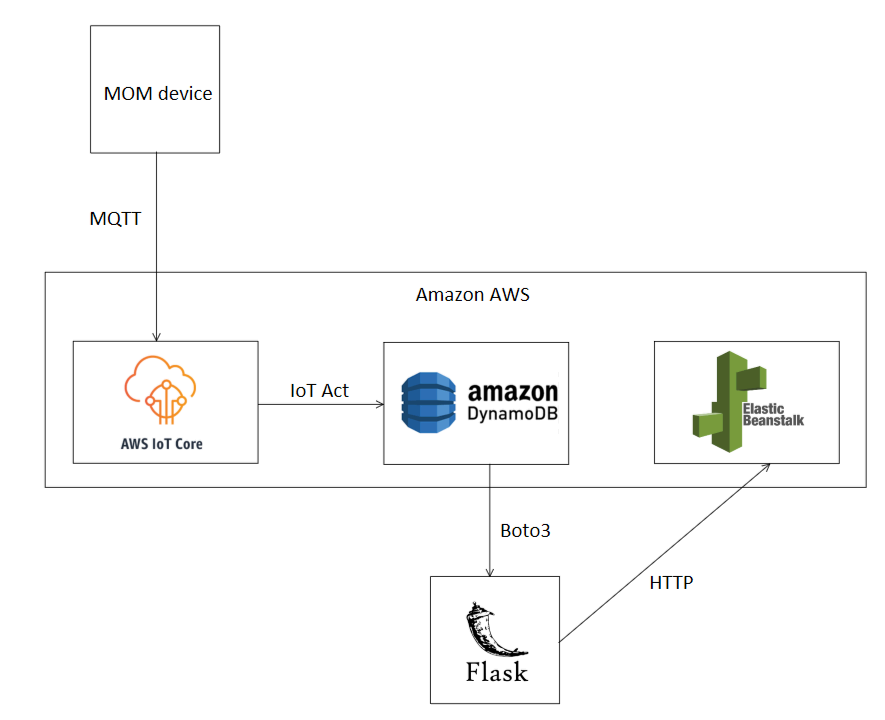
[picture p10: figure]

Figure 6: Block Diagram of the AWS Infrastructure

### 2.5 Occupancy Estimation Algorithm

### 2.5.1 Design Procedure

The simplest approach to occupancy estimation by monitoring Wi-Fi traffic would be simply counting the number of devices seen within set periods. With enough fine-tuning, this approach would be sufficient to determine the relative occupancy of a space (i.e. how full the space is represented as a percentage). However, the primary goal of the project is to estimate the exact number of people with at least 80% accuracy.

Monitoring Wi-Fi traffic to estimate the exact number of people in an enclosed area requires careful observation of multiple factors. In addition to the number of Wi-Fi enabled devices seen, it also requires observing the signal strength of each seen device, the dimensions of the enclosed area, the timestamps of when each device was seen, and devices that may be part of the environment (e.g. wireless routers, Wi-Fi enabled printers, digital signage). By accounting for these factors, we are able to mitigate the possibility of overcounting the number of people in the area the device is deployed in.

### 2.5.2 Design Details

The aggregation of these factors allows for a more accurate estimation of the number of people in the area. Since we are using all of these factors, we came up with a model that determines the probability that a seen device contributes to exactly one occupant in the room. This model focuses on three possibilities. The first is if the seen device belongs to a person in the target area and not outside the area, the second is if the seen device could be the person's second device, and the third is if the seen device belongs to the environment as stated previously. These are illustrated in the flowchart in Figure 7 below.

To calculate the probabilities, conditional checks are used in conjunction with the timestamps and signal strength of each seen device's probe request. Devices which haven't been seen after a set period, fall outside of the defined signal strength range, or are part of the environment are given a probability of zero. The stronger the device signal and the more recently the device has been detected, the higher the probability. The probabilities are recalculated multiple times in one second, so as time goes on, the probability assigned to a device may decrease.

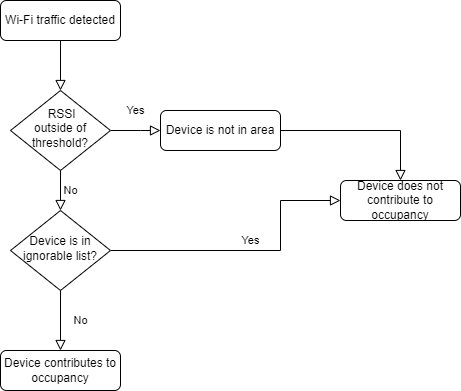
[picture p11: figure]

Figure 7: Probability Model Flowchart

## 3 Design Verification

The Requirements & Verification Tables can be found in Appendix A.

### 3.1 Control Unit

- The microcontroller on the MOM device powers on and is able to be programmed by a development computer over USB.

This requirement confirms that the device not only works, but is also able to be programmed with the monitoring program. After running through the verification of the Control Unit, we were able to connect it to a development computer to program it with the verification program and power it, verifying this requirement.

### 3.2 Radio Scanner Suite

There were no requirements to verify for the Radio Scanner Suite as it only consisted of the included Wi-Fi interface of the ESP32-S3-MINI-1 SoC.

### 3.3 Power Supply

### 3.3.1 Battery Charger

- The battery charger must be able to charge the battery to at least 3.7 V, but no more than 4.3 V, in 12 hours or less.

In the event of intermittent wall power disruptions, the battery needs to be as charged as possible in order to power the device for at least one hour. As we can see in Table 1 below, this requirement was met. The battery was charged to 3.7 V within 20 minutes, and charged to 4.19 V within 80 minutes. After being plugged in for an additional 100 minutes, the battery charging circuit stopped so that the battery did not overcharge, verifying this requirement.

Table 1: Battery Voltage While Charging Over Time
Time (minutes) | Battery Voltage (V)
0 | 3.09
20 | 3.71
80 | 4.19
180 | 4.1

- The battery charger must be able to report the battery level to the control unit with at least 80% accuracy.

This requirement is important so that if there was an issue with the device, we could determine if it is a battery issue or not by checking the battery's state of charge. During the verification, the multimeter reported a battery voltage of 4.15 V, while the battery charger reported a voltage of 4.14 V, which is within the tolerance of 20%.

### 3.3.2 Power Source Decision Circuit

- The decision circuit must be able to switch to wall power and supply a stable voltage of 3.3 V ± 0.3V.

This requirement ensures the safe transition from battery power, or no power at all, to wall power. After performing the verification steps, the multimeter probe read 3.32 V while the device was connected to wall power. 3.32 V is within the specified tolerance, verifying this requirement.

- The decision circuit must be able to switch to battery power and supply a stable voltage of 3.3V ± 0.3V.

The transition from wall power to battery power needs to keep the SoC at a safe voltage level. After performing the verification steps, the multimeter probe read 3.31 V while the device was powered only by the battery. 3.31 V is within the specified tolerance, verifying this requirement.

### 3.4 IoT Cloud

### 3.4.1 MQTT Service

- Each MOM device should be able to connect to AWS servers with a round-trip latency of no greater than 500 milliseconds.

If the round-trip latency from the device to AWS is greater than 500 milliseconds, that may be indicative of a weak connection. This requirement enforces a reliable connection before sending occupancy data. As we ran the ping tests as part of the verification for this requirement, the average round-trip latencies were all less than 30 milliseconds while connected to IllinoisNet.

- Each MOM device should be able to post three messages to the MQTT service in no more than 10 seconds.

We want to ensure the stability of the cloud infrastructure should multiple devices publish to the MQTT service in rapid succession. As part of the verification for this requirement, a MOM device attempts to publish three messages all within one second. The MQTT service was able to handle all three messages and relay them in slightly more than one second, which is less than ten seconds.

### 3.4.2 Web Application

- The user interface of the application loads in less than 10 seconds.

An application which loads quickly provides an enhanced user experience. As part of the verification for this requirement, we simply access the web application and see how long it takes to load. On every occasion, it loads in less than ten seconds.

- The user interface must be responsive (i.e. scalable and readable on smartphones, tablets, laptops, and computer monitors).

Responsive web applications enhance the user experience by making it easy to read the content no matter what device is being used. The verification for this requirement is simply making sure that the contents of the web application are properly scaled to the screen size of the device it is accessing. This requirement was verified, and screenshots of this can be seen in Appendix B.

## 4 Cost and Schedule

### 4.1 Parts

The parts list for a single MOM device can be seen in Table 2 below. Many of the parts are optional, such as the enclosure, and many of them can be repurposed from other products, such as the USB wall adapter and cable. Omitting optional and repurposed parts from the cost would greatly reduce the cost of a single MOM device. If one is planning on building multiple devices, additional discounts are given by purchasing these parts in bulk from distributors such as Digi-Key or Mouser Electronics.

Table 2: Cost Breakdown Table
Part (With Purchase Link) | Quantity (per node) | Extended Price (per node)
ESP32-S3-MINI-1-N8 SoC | 1 | $3.41
GCT USB 2.0 Type-C Receptacle | 1 | $0.94
AP2112 (3.3V) Linear Voltage Regulator | 1 | $0.42
MCP73831-2ACI Battery Charge Controller | 1 | $0.80
MAX17048G+T10 Battery Fuel Gauge | 1 | $3.34
3.7V 500mAh Li-Po Battery (JST-PH) | 1 | $7.95
2-pin JST-PH Header | 1 | $0.17
DMP2045UQ MOSFET | 1 | $0.53
5A/40V Schottky Diode | 1 | $0.54
Surface Mount Chip Resistor 100KOhm | 2 | $0.20
Surface Mount Chip Resistor 5.1KOhm | 5 | $0.50
Surface Mount Chip Resistor 2KOhm | 1 | $0.10
Surface Mount Capacitor 0.1uF | 1 | $0.36
Surface Mount Capacitor 10uF | 7 | $2.16
Surface Mount Capacitor 1uF | 2 | $0.72
Through-Hole Red LED | 1 | $0.35
(continued on next page)

Through-Hole Yellow LED | 1 | $0.15
Tactile Button Switch | 2 | $0.36
USB Wall Adapter | 1 | $5.00
USB-C to USB-A cable | 1 | $5.89
PCB | 1 | $5.00
LP-51F Polycase (Optional) | 1 | $6.13
Total Parts Cost | | $45.02

### 4.2 Labor

The average salary of a computer engineering graduate from UIUC is $105,352 [9]. Assuming that a full-time engineer has a 40-hr work week and the engineer works an average of 48 weeks per year, then the engineer works 1,920 hours per year. This equates to $54.87 per hour. Our project timeline from here on out is 12 weeks. Assuming we spend 10 hours on this project per week then we would be spending a total of 120 hours on this project to complete it. We can calculate the labor cost per team member using Equation 3 below:

($54. 87/ℎour) * 2. 5 * 120 ℎours = $16, 461 | (3)

From Equation 3, we can see that the labor cost for one team member would be $16,461. Since all three members of our team are computer engineers, then the total labor cost for the team would be $49,383.

## 5 Conclusion

### 5.1 Accomplishments

We believe that this project was an overall success. All high-level and subsystem requirements were met, with the MOM device estimating occupancy with an accuracy of more than 80% during our testing. Additionally, the IoT Cloud infrastructure is scalable should we make more MOM devices and deploy them to monitor additional additional areas.

### 5.2 Uncertainties

Unfortunately, creating a general model that works for any kind of room or enclosed space proved difficult. Trying to detect if a person has multiple Wi-Fi devices is extremely difficult to detect. This is due to the privacy features of modern devices and the fact that using signal strength values to estimate distance yields the radius of a sphere. To make things simple, our algorithm runs under the assumption that the signals it is catching are on the same floor of the building it is deployed on. Even though it is likely to capture signals from devices on adjacent floors, we were able to fine-tune the parameters of our algorithm to overcome these difficulties when deployed in larger rooms. However, when the device is deployed in a smaller room, the accuracy of the algorithm decreases dramatically.

### 5.3 Ethical Considerations

One of the most significant ethical considerations we had to take into account was privacy, which directly relates to section I-1 of the IEEE Code of Ethics [10]. The project was designed with maintaining the privacy of individuals in mind. MOM devices do not read or collect data contained within Wi-Fi packets themselves. The only identifiable data in probe requests are Wi-Fi MAC addresses, which themselves are public information. Wi-Fi MAC addresses can only identify a particular device, but cannot be used to identify an individual.

Pursuant to Section I-2 of the IEEE Code of Ethics [10], students and others in public spaces have the right to know when and where this monitoring is occurring and how our devices work. Therefore, if we ever put our MOM devices to production in any study spaces, there would be a clear sign to indicate to the occupants of the room the intention of the device and how it collects data.

Finally, the health and safety of the public as described in Section I-1 of the IEEE Code of Ethics
[10] is paramount. As each MOM device will have lithium-polymer batteries, it is important to ensure that they stay in safe operating conditions. We have performed extensive testing to make sure the battery cannot be overcharged, the results of which can be seen in Appendix E.

### 5.4 Future Work

There are various improvements and applications we can derive from our initial prototype of the MOM device. Though our current model is successful, we can develop a stronger and more accurate model to improve the overall efficacy of the occupancy approximation determination. For instance, we can deploy several MOM devices (as opposed to just one) over an extended stretch of time, accruing more data. This could help fine tune the precision of the room’s occupancy metrics.

Additionally, our MOM device relied on probing Wi-Fi signals to estimate occupancy. We can expand this by probing Bluetooth signals as well. Then we can compute a “weighted average” between cumulative Bluetooth and Wi-Fi traffic to better capture how busy a specific room is.

Right now, our project only supports one room. However, our AWS and web application infrastructure was set up in a manner where it can be easily scalable if needed. Therefore, if we can expand this project to a wider scale, then we could put a MOM device in each study room that we would like to monitor occupancy data in. The web application would also be updated appropriately to support this and would have a page navigation where the user is able to browse through and select the room of interest to them.

Another future improvement could be to include a graph of the most popular times when a room is busy and usually open. This graph would go right below our occupancy pie chart on our web application. The graph would forecast when a room is most available based on historical occupancy data that we would have collected and stored in our database. Using this approach we could get a rough estimate of the number of people for a given future time. To forecast future occupancy, we could also use more sophisticated models such as an LSTM (Long Short-Term Memory) model which is a type of recurrent neural network that has vast applications when given time series data as inputs [11]. It can predict pretty accurately when given proper data points and trained appropriately.

## References

[1] M. Thaler, C. Barber, and T. Pittman, "Students on Libraries - Student Views on the Academic Library of Today and Tomorrow," Gensler, 2015. Accessed: Sep. 14, 2022. [Online]. Available: https://www.gensler.com/doc/students-on-libraries
[2] A. Raychawdhuri. "Lack of study spaces at UCLA imposes unnecessary stress on students." The Daily Bruin, Feb. 28, 2019. Accessed: Sep. 14, 2022. [Online]. Available: https://dailybruin.com/2019/02/28/lack-of-study-spaces-at-ucla-imposes-unnecessary-str ess-on-students (https://dailybruin.com/2019/02/28/lack-of-study-spaces-at-ucla-imposes-unnecessary-stress-on-students)
[3] L. Oliveira, D. Schneider, J. De Souza, and W. Shen, "Mobile Device Detection Through WiFi Probe Request Analysis," in IEEE Access, vol. 7, pp. 98579-98588, 2019, doi: 10.1109/ACCESS.2019.2925406.
[4] Occuspace, Inc. "Waitz," 2019. Accessed: Sep. 12, 2022. [Online]. Available: https://waitz.io/
[5] LiveOverflow, Berlin, Germany. Student Finds Hidden Devices in the College Library -Are They Nefarious?, Nov. 9, 2018. Accessed: Sep. 12, 2022. [Online Video] Available: https://www.youtube.com/watch?v=UeAKTjx_eKA
[6] E. Upton, "Production and supply-chain update," Raspberry Pi, Apr. 4, 2022. Accessed: Sep. 12, 2022. [Online]. Available: https://www.raspberrypi.com/news/production-and-supply-chain-update/
[7] "ESP32-S3-MINI-1 ESP32-S3 MINI-1U Datasheet", Espressif, Sep. 2022. Accessed: Sep. 12, 2022. [Online]. Available: https://www.espressif.com/sites/default/files/documentation/esp32-s3-mini-1_mini-1u_datasheet_en.pdf (https://www.espressif.com/sites/default/files/documentation/esp32-s3-mini-1_mini-1u_datasheet_en.pdf)
[8] "MCP73831/MCP73832 Data Sheet," Microchip Technology, June 2020, Accessed: Nov. 2, 2022. [Online]. Available: https://ww1.microchip.com/downloads/en/DeviceDoc/MCP73831-Family-Data-Sheet-D S20001984H.pdf (https://ww1.microchip.com/downloads/en/DeviceDoc/MCP73831-Family-Data-Sheet-DS20001984H.pdf)
[9] The Grainger College of Engineering, “Computer Engineering,” University of Illinois Urbana-Champaign. Accessed: Sep. 25, 2022. [Online]. Available: https://grainger.illinois.edu/academics/undergraduate/majors-and-minors/computer-engi neering (https://grainger.illinois.edu/academics/undergraduate/majors-and-minors/computer-engineering)

[10] IEEE Board of Directors, "IEEE Code of Ethics," Institute of Electrical and Electronics Engineers, 2020. Accessed: Sep. 14, 2022. [Online]. Available: https://www.ieee.org/about/corporate/governance/p7-8.html
[11] J. Brownlee. “How to Develop LSTM Models for Time Series Forecasting,” Machine Learning Mastery. Accessed: Nov. 22, 2022. [Online]. Available: https://machinelearningmastery.com/how-to-develop-lstm-models-for-time-series-forecasting/ (https://machinelearningmastery.com/how-to-develop-lstm-models-for-time-series-forecasting/)

## Appendix A: Requirements & Verification Tables

Table 3: Control Unit RV Table
Requirements | Verification | Verified
1. The microcontroller on the MOM device powers on and is able to be programmed by a development computer over USB. | 1A. Connect the device with a USB port on a development computer. 1B. Create a simple "Hello World!" program that involves blinking the LED on the microcontroller's GPIO13 pin. 1C. Flash the program onto the microcontroller. Verify that the program is executing correctly and the LED on GPIO13 is blinking. | Y

Table 4: Battery Charger RV Table
Requirements | Verification | Verified
1. The battery charger must be able to
charge the battery to at least 3.7V, but no more than 4.3V, in 12 hours or less. | 1A. Allow the battery to discharge over time until it reads 3.1V. 1B. Plug in the device to wall power. Monitor battery voltage using a multimeter periodically. When the battery voltage reads 3.7V through an oscilloscope or multimeter, record the charge cycle time and verify that it is less than 12 hours. 1C. Allow the battery to continue charging until it has reached around 4.2V. Measure the battery voltage using either an oscilloscope or multimeter and ensure that the battery reads 4.2V ±

0.1V.
| 1D. Allow the battery to continue charging for an additional hour. Measure the battery voltage using either an oscilloscope or multimeter and ensure that the battery reads no more than 4.3V.

Y

(continued on next page)

2. The battery charger must be able to report the battery level to the control unit with at least 80% accuracy.

2A. Write a simple program to print the voltage of the battery. Flash this program onto the microcontroller.
2B. While the program is running, measure the battery voltage by probing it using a multimeter or oscilloscope. 2C. Ensure that the value printed by the microcontroller is within 80% of the voltage read by the oscilloscope or multimeter.

Y

Table 5: Power Source Decision Circuit RV Table
Requirements | Verification | Verified
1. The decision circuit must be able to switch to wall power and supply a stable voltage of 3.3V ± 0.3V. | 1A. Connect the device to wall power and boot it. 1B. Using a multimeter or oscilloscope, probe the Vout pin of the voltage regulator with the positive probe and a GND pin with the negative probe. 1C. Confirm that the voltage read is 3.3V ± 0.3V. | Y
2. The decision circuit must be able to switch to battery power and supply a stable voltage of 3.3V ± 0.3V. | 2A. Ensure that the battery backup is connected and disconnect the device from wall power. Boot the device if it hasn't already been booted. 2B. Using a multimeter or oscilloscope, probe the Vout pin of the voltage regulator with the positive probe and a GND pin with the negative probe. 2C. Confirm that the voltage read is 3.3V ± 0.3V. | Y

Table 6: AWS MQTT Service RV Table
Requirements | Verification | Verified
1. Each MOM device should be able to connect to AWS servers with a round-trip latency of no greater than 500 milliseconds. | 1A. Create a simple program which can ping AWS servers and report the round-trip latency. 1B. Connect the microcontroller to the development computer and flash the program to the microcontroller. 1C. Run the ping program and confirm that the round-trip latency is no greater than 500 milliseconds. | Y
2. Each MOM device should be able to post three messages to the MQTT service in no more than 10 seconds. | 2A. Create a simple program which pushes three separate messages to the MQTT Service. 2B. Connect the microcontroller to the development computer and flash the program to the microcontroller. 2C. Set up the MQTT service to process occupancy information events. 2D. Run the program. Once the program finishes, confirm that all three events have been processed within 15 seconds ± 5 seconds in the AWS MQTT Message Monitor. | Y

Table 7: Web Application RV Table
Requirements | Verification | Verified
1. The user interface of the application loads in less than 10 seconds. | 1A. Open a new tab on any device with a web browser that has a strong connection to the internet. 1B. Enter the address of the web application and start a stopwatch. 1C. Confirm that the web application's user interface loads in less than 10 seconds. | Y
2. The user interface must be responsive (i.e. scalable and readable on smartphones, tablets, laptops, and computer monitors).

2A. Open a new tab on a smartphone that has a strong connection to the internet. 2B. Enter the address of the web application.
2C. Confirm that the user interface is readable and properly scaled to the size of the smartphone.
2D. Open a new tab on a laptop that has a strong connection to the internet.
2E. Enter the URL/address of the application.
2F. Confirm that the user interface is readable and properly scaled to the size of the laptop's display.

Y

## Appendix B: Web Application User Interface

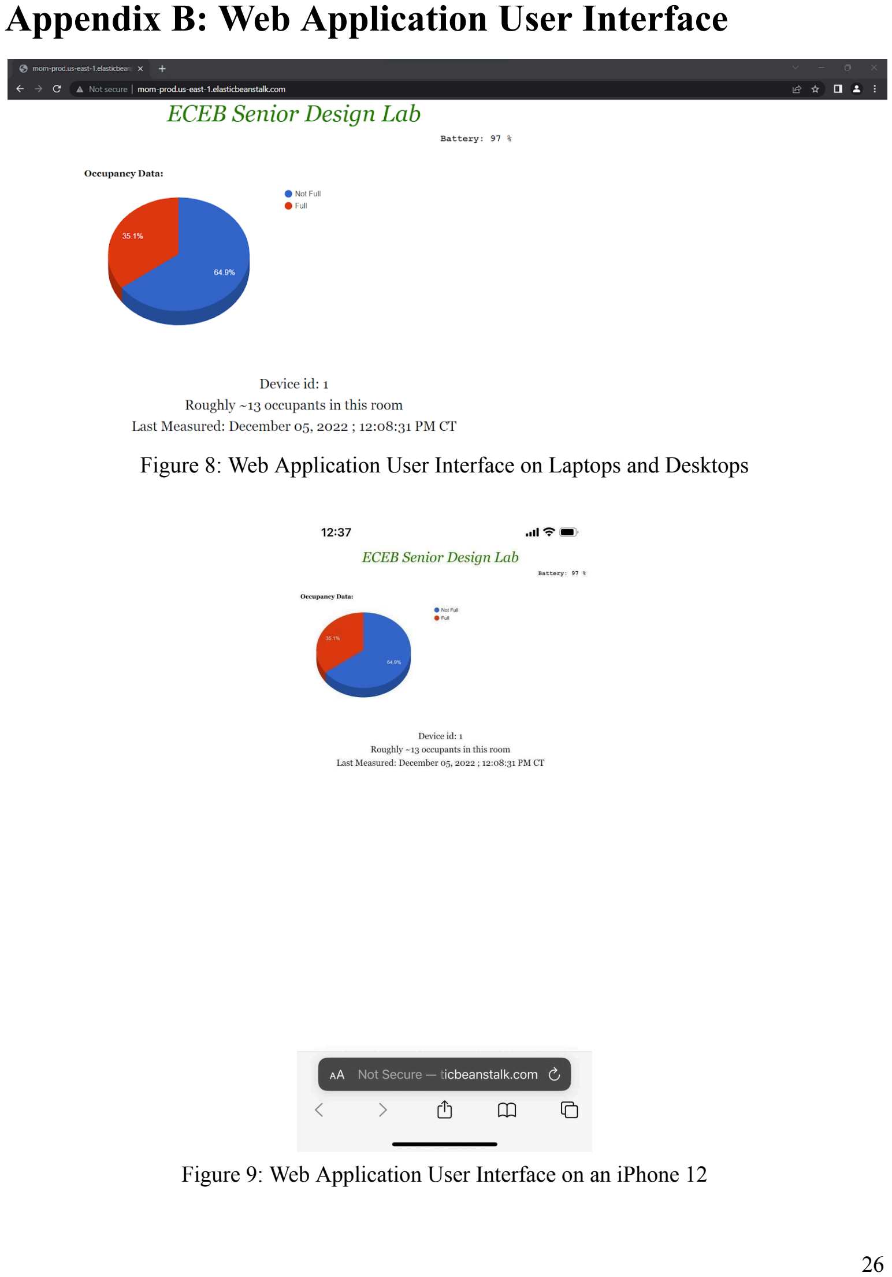
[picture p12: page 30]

Figure 8: Web Application User Interface on Laptops and Desktops

Figure 9: Web Application User Interface on an iPhone 12

## Appendix C: Schematic, PCB, and Final Product

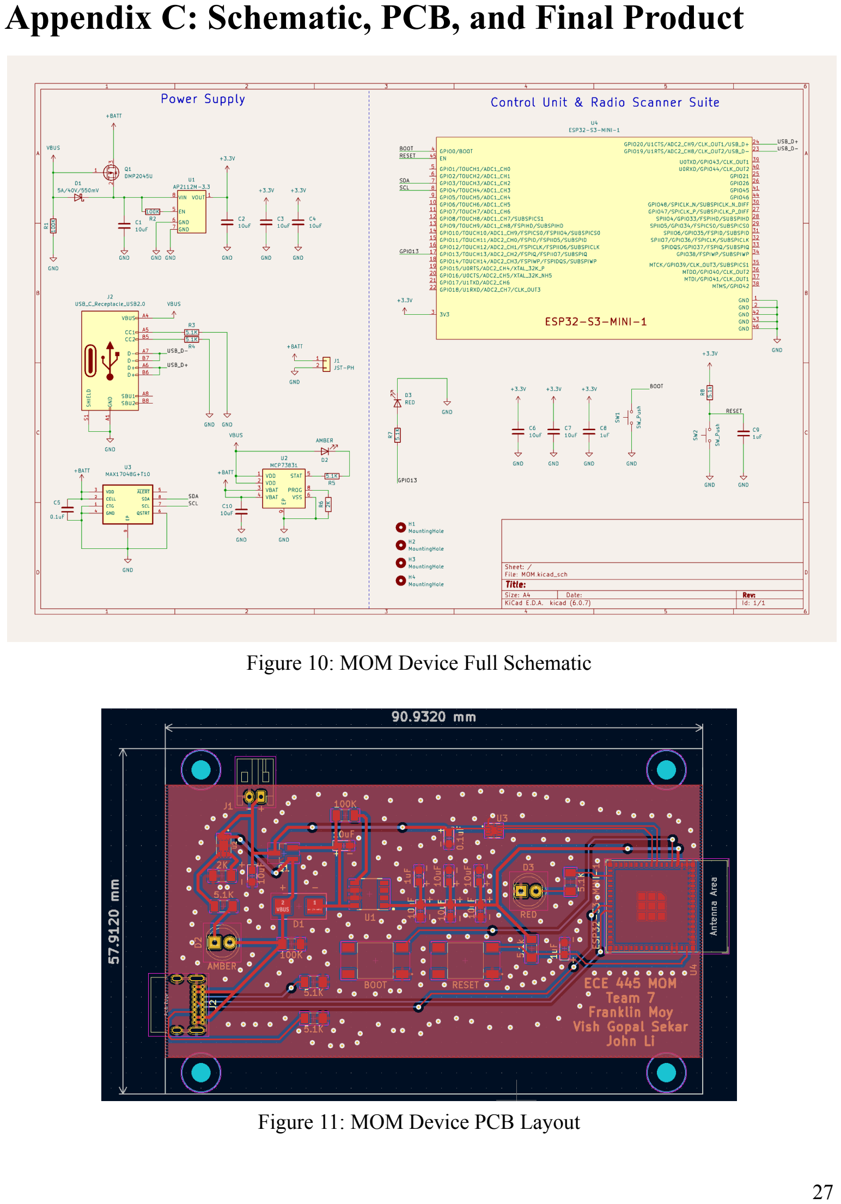
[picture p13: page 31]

Figure 10: MOM Device Full Schematic

Figure 11: MOM Device PCB Layout

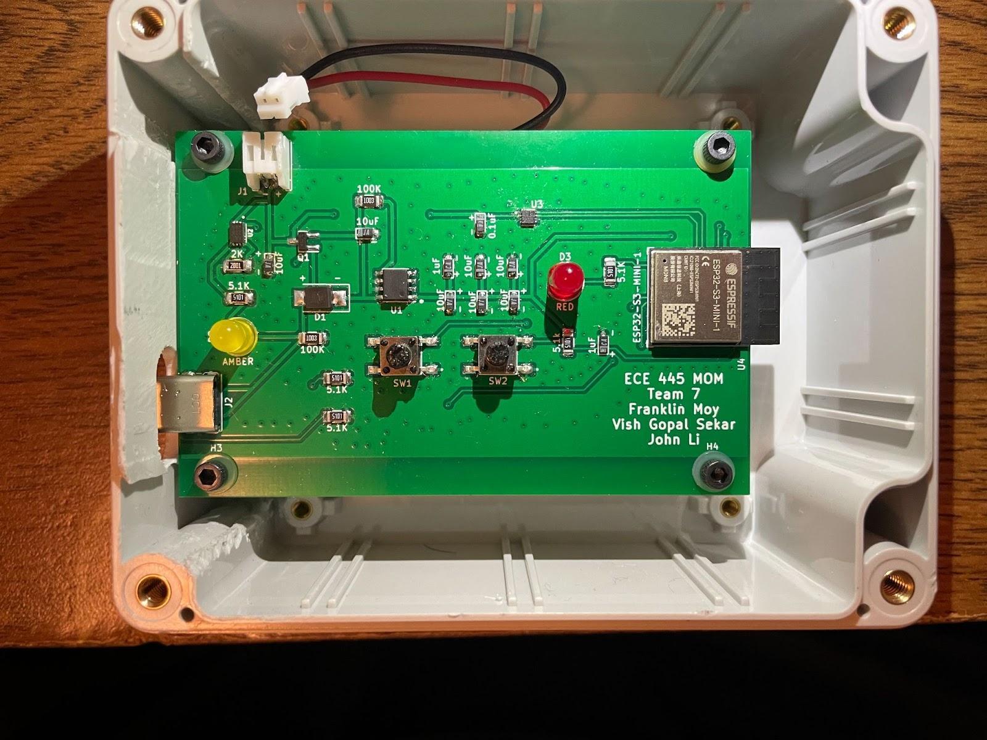
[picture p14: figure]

\
Figure 12: MOM Device in Enclosure

## Appendix D: Battery Test Results

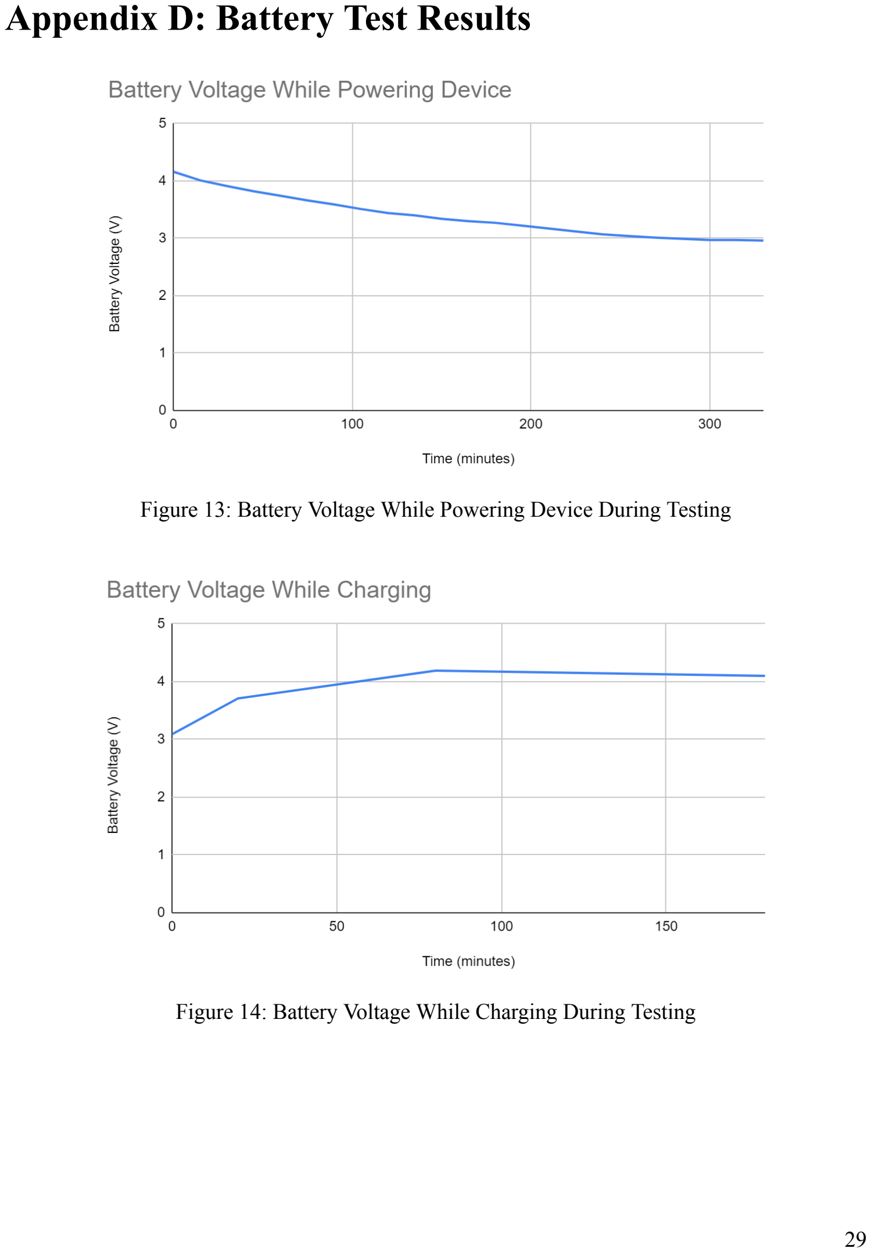
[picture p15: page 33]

Figure 13: Battery Voltage While Powering Device During Testing

Figure 14: Battery Voltage While Charging During Testing

## Appendix E: Battery Charger Overcharge Test

An additional current cutoff test was conducted to ensure the battery charger would not overcharge the backup battery. Once a lithium-polymer battery reaches about 4.2 V, the charging circuit should cut off power to the battery to maintain the health of the battery. Overcharging a lithium-polymer battery can lead to swelling and fire.

A circuit imitating a battery was created and connected to the battery header of the device. The voltage of the imitation battery can be adjusted using a potentiometer. An ammeter was connected in series between the charge output of the battery charger and the positive terminal of the imitation battery to measure the charge current at various voltages. The results of the test can be seen in Table 8 below, which shows that the battery charger properly cuts off power when the battery voltage goes above 4.2 V.

Table 8: Mock Battery Charging Test Readings
Mock Battery Voltage (V) | Charge Current (A)
3.31021 | 0.524102
3.72014 | 0.523611
4.06172 | 0.523125
4.21920 | 0.000004
4.30182 | 0.000004

## Appendix F: Monitoring Program Flow

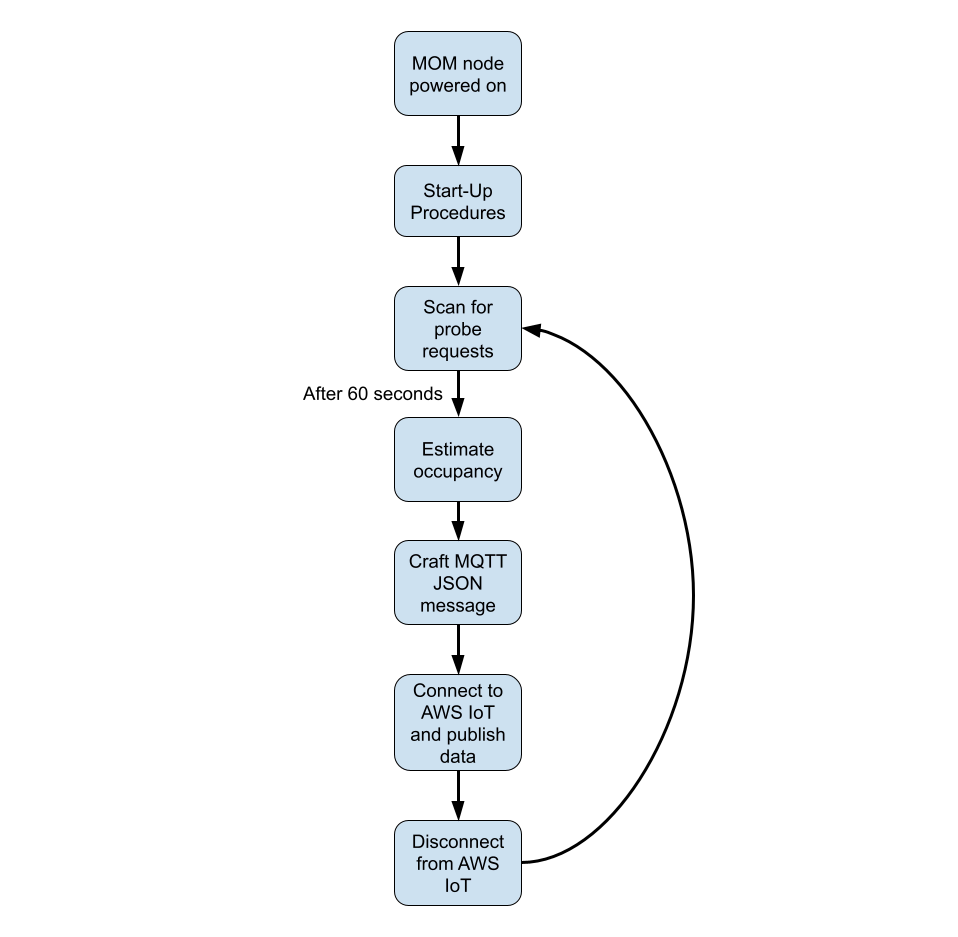
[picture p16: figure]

Figure 15: Flow of the Monitoring Program

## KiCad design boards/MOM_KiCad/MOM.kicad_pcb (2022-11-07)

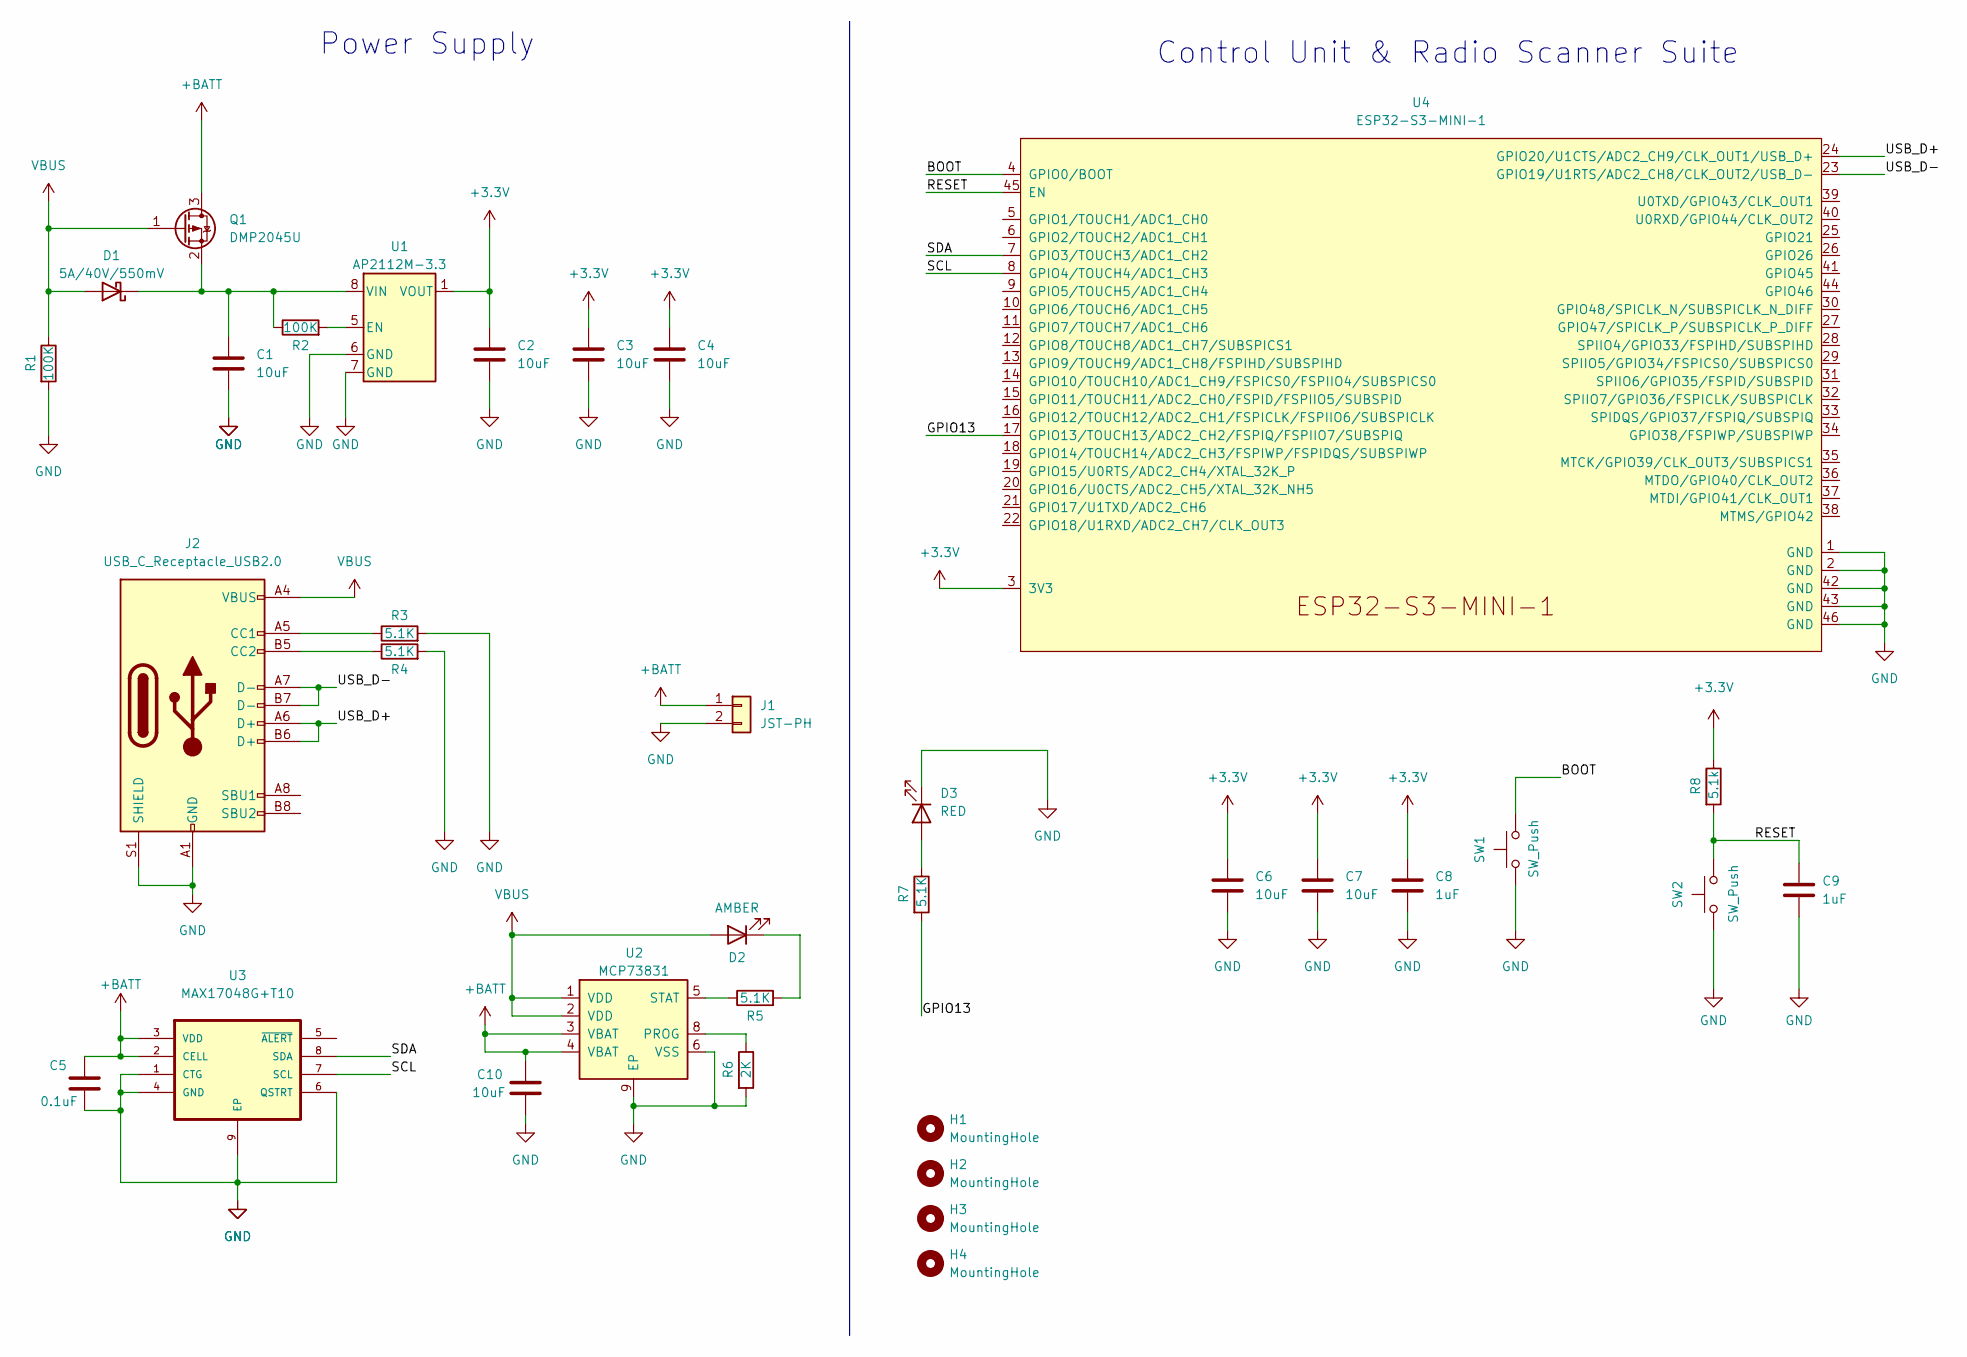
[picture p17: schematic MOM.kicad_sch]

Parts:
C1, C2, C3, C4, C6, C7, C10: 10uF; CP_EIA-2012-12_Kemet-R_Pad1.30x1.05mm_HandSolder
C5: 0.1uF; CP_EIA-2012-12_Kemet-R_Pad1.30x1.05mm_HandSolder
C8, C9: 1uF; CP_EIA-2012-12_Kemet-R_Pad1.30x1.05mm_HandSolder
D1: 5A/40V/550mV; D_SMBF_Handsoldering
D2: AMBER; LED_D5.0mm
D3: RED; LED_D5.0mm
H1, H2, H3, H4: MountingHole; MountingHole_3.2mm_M3
J1: JST-PH; JST_PH_S2B-PH-K_1x02_P2.00mm_Horizontal
J2: USB_C_Receptacle_USB2.0; USB_C_Receptacle_GCT_USB4085
Q1: DMP2045U; SOT-23_Handsoldering
R1, R2: 100K; R_1206_3216Metric_Pad1.30x1.75mm_HandSolder
R3, R4, R5, R7: 5.1K; R_1206_3216Metric_Pad1.30x1.75mm_HandSolder
R6: 2K; R_1206_3216Metric_Pad1.30x1.75mm_HandSolder
R8: 5.1k; R_1206_3216Metric_Pad1.30x1.75mm_HandSolder
SW1, SW2: SW_Push; SW_TS04-66-65-BK-160-SMT
U1: AP2112M-3.3; Diodes_SO-8
U2: MCP73831; SON50P200X300X100-9N
U3: MAX17048G+T10; SON50P200X200X80-9N
U4: ESP32-S3-MINI-1

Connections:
+3.3V: C2.1, C3.1, C4.1, C6.1, C7.1, C8.1, R8.1, U1.1 (VOUT), U4.3 (3V3)
+BATT: C5.1, C10.1, J1.1, Q1.3 (D), U2.3 (VBAT), U2.4 (VBAT), U3.2 (CELL), U3.3 (VDD)
/BOOT: SW1.2, U4.4 (GPIO0/BOOT)
/GPIO13: R7.2, U4.17 (GPIO13/TOUCH13/ADC2_CH2/FSPIQ/FSPIIO7/S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)
/RESET: C9.1, R8.2, SW2.2, U4.45 (EN)
/SCL: U3.7 (SCL), U4.8 (GPIO4/TOUCH4/ADC1_CH3)
/SDA: U3.8 (SDA), U4.7 (GPIO3/TOUCH3/ADC1_CH2)
/USB_D+: J2.A6 (D+), J2.B6 (D+), U4.24 (GPIO20/U1CTS/ADC2_CH9/CLK_OUT1/USB_D+)
/USB_D-: J2.A7 (D-), J2.B7 (D-), U4.23 (GPIO19/U1RTS/ADC2_CH8/CLK_OUT2/USB_D-)
GND: C1.2, C2.2, C3.2, C4.2, C5.2, C6.2, C7.2, C8.2, C9.2, C10.2, D3.1 (K), J1.2, J2.A1 (GND), J2.A12 (GND), J2.B1 (GND), J2.B12 (GND), J2.S1 (SHIELD), R1.2, R3.2, R4.2, R6.2, SW1.1, SW2.1, U1.6 (GND), U1.7 (GND), U2.6 (VSS), U2.9 (EP), U3.1 (CTG), U3.4 (GND), U3.6 (QSTRT), U3.9 (EP), U4.1 (GND), U4.2 (GND), U4.42 (GND), U4.43 (GND), U4.46 (GND)
unnamed: C1.1, D1.1 (K), Q1.2 (S), R2.1, U1.8 (VIN)
unnamed: D2.1 (K), R5.2
unnamed: D3.2 (A), R7.1
unnamed: J2.A5 (CC1), R3.1
unnamed: J2.B5 (CC2), R4.1
unnamed: R2.2, U1.5 (EN)
unnamed: R5.1, U2.5 (STAT)
unnamed: R6.1, U2.8 (PROG)
VBUS: D1.2 (A), D2.2 (A), J2.A4 (VBUS), J2.A9 (VBUS), J2.B4 (VBUS), J2.B9 (VBUS), Q1.1 (G), R1.1, U2.1 (VDD), U2.2 (VDD)

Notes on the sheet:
Power Supply
Control Unit & Radio Scanner Suite

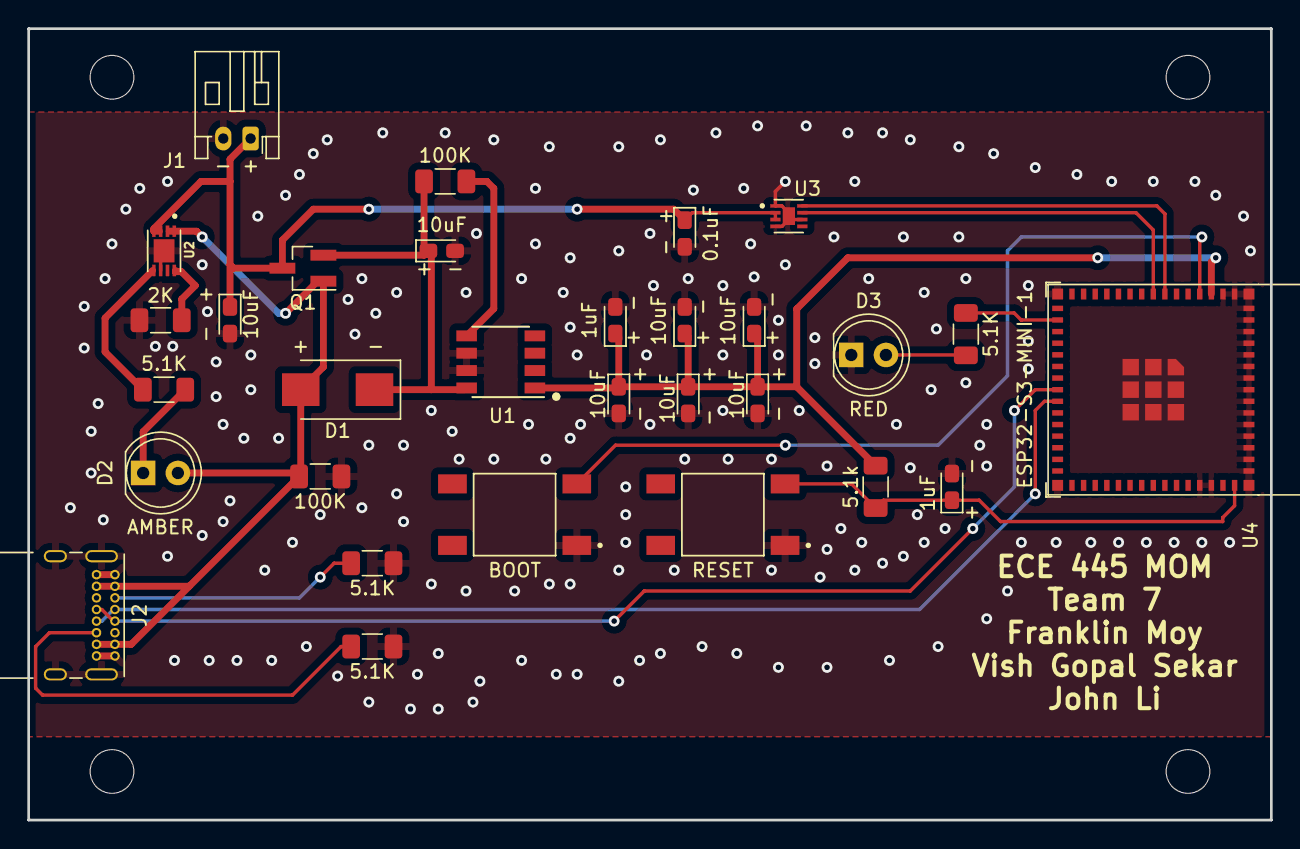
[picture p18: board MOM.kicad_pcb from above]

Board: 2 copper layers, 90.9 x 57.9 mm, 34 parts (0 on the bottom side), 19 nets.

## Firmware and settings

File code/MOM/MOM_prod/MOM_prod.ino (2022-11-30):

#include "secrets.h"
#include "wifi_scanner.h"

#include <ArduinoJson.h>
#include <ESP32Ping.h>
#include <SparkFun_MAX1704x_Fuel_Gauge_Arduino_Library.h>

#define LED_GPIO_PIN            13
#define OCCU_PUBLISH_TOPIC      "MOM/occupancy"
#define LOCATION                "ECEB Senior Design Lab"
#define MIN_RSSI                -58
#define TARGET_RSSI             -42
#define FIXED_POINT_FACTOR      100
#define CONTRIBUTION_FACTOR     (FIXED_POINT_FACTOR / 20)


SFE_MAX1704X lipo;
int batteryPercent;
bool batteryGaugeConnected;
uint8_t channel = 11;
uint64_t last_transmission_to_aws;
LinkedList<mac_list_item_t> mac_list = LinkedList<mac_list_item_t>();
WiFiClientSecure net = WiFiClientSecure();
MQTTClient mqttClient = MQTTClient(256);

void batteryGaugeInit() {
  Wire.begin(3, 4); // Battery gauge SDA and SCL on GPIO3 and 4, respectively
  int stateOfCharge;
  batteryGaugeConnected = lipo.begin();
  if(batteryGaugeConnected == false) {
    printf("MAX battery fuel gauge not detected. Battery percent will read -1\n");
    batteryPercent = -1;
  }
  lipo.quickStart();
}

bool connectWiFi() {
  WiFi.begin(WIFI_SSID, WIFI_PASSWORD);
  printf("Connecting to Wi-Fi.");
  uint64_t connect_time_start = esp_timer_get_time() / 1000000; // Seconds since boot
  while (WiFi.status() != WL_CONNECTED) {
    delay(200);
    printf(".");
    // Enforce 5-second timeout
    if (esp_timer_get_time() / 1000000 - connect_time_start > 5) {
      printf("Timed out while connecting to %s!\n", WIFI_SSID);
      WiFi.disconnect();
      return false;
    }
  }
  printf(" Connected!\n");
  return true;
}

void pingTest() {
  bool ret = Ping.ping(AWS_IOT_ENDPOINT, 10);
  float avg_time_ms = Ping.averageTime();
  printf("Ping test finished. Average ping time: %f milliseconds\n", avg_time_ms);
}

bool connectAWS() {
  // Set creds to connect to AWS IoT
  net.setCACert(AWS_CERT_CA);
  net.setCertificate(AWS_CERT_CRT);
  net.setPrivateKey(AWS_CERT_PRIVATE);

  mqttClient.begin(AWS_IOT_ENDPOINT, 8883, net);
  printf("Connecting to AWS IoT.");

  while (!mqttClient.connect(THINGNAME)) {
    printf(".");
    delay(10);
  }

  if (!mqttClient.connected()) {
    printf("\nTimed out while connecting to AWS IoT Core!");
    return false;
  }

  printf(" Connected!\n");
  return true;
}

void disconnectAWS() {
  bool disconnected = mqttClient.disconnect();
  printf("Disconnected from AWS IoT.\n");
}

int estimateOccupancy() {
  mac_list_item_t curr_mac;
  int sum = 0;
  int diff, contribution;
  uint64_t time_alive;
  uint64_t curr_time = esp_timer_get_time() / 1000;
  if (mac_list.size() >= 5) {
    sum = 1;
  }
  for (int i = 0; i < mac_list.size(); i++) {
    curr_mac = mac_list.get(i);
    if (curr_mac.rssi >= TARGET_RSSI) {
      contribution = FIXED_POINT_FACTOR;
    }
    else if (curr_mac.reappearance) {
      contribution = FIXED_POINT_FACTOR - 20;
      time_alive = curr_time - curr_mac.timestamp;
      contribution -= (int)(time_alive * FIXED_POINT_FACTOR / curr_mac.ttl / 2);
    }
    else {
      diff = curr_mac.rssi - MIN_RSSI;
      contribution = diff * CONTRIBUTION_FACTOR + 1;
      time_alive = curr_time - curr_mac.timestamp;
      contribution -= (int)(time_alive * FIXED_POINT_FACTOR / curr_mac.ttl / 2);
    }
    if (contribution < 0) {
      contribution = 0;
    }
    sum += contribution;
  }
  sum /= FIXED_POINT_FACTOR;
  if (mac_list.size() >= 5 && sum >= 19 ) {
    sum -= 1;
  }
  if (sum >= 20) {
    sum /= 2;
  }
  return sum;
}

void publishMessage() {
  if (connectAWS()) {
    StaticJsonDocument<200> doc;
    doc["location"] = LOCATION;
    doc["occupancy"] = estimateOccupancy();
    if (batteryGaugeConnected) {
      batteryPercent = (int) lipo.getSOC();
      if (batteryPercent > 100) {
        batteryPercent = 100;
      }
    }
    doc["battery"] = batteryPercent;
    char jsonBuffer[512];
    serializeJson(doc, jsonBuffer);

    mqttClient.publish(OCCU_PUBLISH_TOPIC, jsonBuffer);
    disconnectAWS();
    printf("Published {\"location\": %s, \"occupancy\": %d, \"battery\": %d} to %s\n", LOCATION, estimateOccupancy(), batteryPercent, OCCU_PUBLISH_TOPIC);
  }
}

bool is_ignorable_oui(uint8_t oui0, uint8_t oui1, uint8_t oui2) {
  int match_count;
  for (int i = 0; i < NUM_IGNORABLE_OUIS; i++) {
    match_count = 0;
    if (ignorable_ouis[i][0] == oui0) {
      match_count++;
    }
    if (ignorable_ouis[i][1] == oui1) {
      match_count++;
    }
    if (ignorable_ouis[i][2] == oui2) {
      match_count++;
    }
    if (match_count == BYTES_IN_OUI) {
      return true;
    }
  }
  return false;
}

void add_mac_to_list(uint8_t mac0, uint8_t mac1, uint8_t mac2, uint8_t mac3, uint8_t mac4, uint8_t mac5, uint64_t timestamp, int8_t rssi) {
  mac_list_item_t seen_mac;
  int i;
  if (is_ignorable_oui(mac0, mac1, mac2)) {
    return;
  }
  seen_mac.mac_addr[0] = mac0;
  seen_mac.mac_addr[1] = mac1;
  seen_mac.mac_addr[2] = mac2;
  seen_mac.mac_addr[3] = mac3;
  seen_mac.mac_addr[4] = mac4;
  seen_mac.mac_addr[5] = mac5;
  seen_mac.timestamp = timestamp;
  seen_mac.rssi = rssi;
  seen_mac.reappearance = false;
  // If the OUI's local bit is set, it's likely randomized
  seen_mac.is_random = (mac0 & 0b00000010); 
  if (rssi < TARGET_RSSI) {
    seen_mac.ttl = TTL_1_MIN + 40000;
  }
  else {
    seen_mac.ttl = TTL_1_MIN + 150000;
  }

  for (i = 0; i < mac_list.size(); i++) {
    mac_list_item_t curr = mac_list.get(i);
    if (curr.mac_addr[0] == mac0 && curr.mac_addr[1] == mac1 && curr.mac_addr[2] == mac2 && 
      curr.mac_addr[3] == mac3 && curr.mac_addr[4] == mac4 && curr.mac_addr[5] == mac5) {
      seen_mac.reappearance = true;
      mac_list.set(i, seen_mac);
      break;
    }
  }
  if (i == mac_list.size()) {
    mac_list.add(seen_mac);
  }
}

void print_seen_macs() {
  mac_list_item_t curr;
  printf("%d seen MACs as of uptime %llu:\n", mac_list.size(), esp_timer_get_time() / 1000);
  for (int i = 0; i < mac_list.size(); i++) {
    curr = mac_list.get(i);
    printf("%02x:%02x:%02x:%02x:%02x:%02x at time = %llu with RSSI = %d and is_random = %d\n", curr.mac_addr[0], curr.mac_addr[1], curr.mac_addr[2], curr.mac_addr[3], curr.mac_addr[4], curr.mac_addr[5], curr.timestamp, curr.rssi, curr.is_random);
  }
  printf("Estimated occupancy: %d\n", estimateOccupancy());
}

void remove_departed_macs() {
  mac_list_item_t curr;
  for (int i = 0; i < mac_list.size(); i++) {
    curr = mac_list.get(i);
    // Remove if this MAC has gone over its TTL
    if (esp_timer_get_time() / 1000 - curr.timestamp >= curr.ttl) {
      mac_list.remove(i);
      i--;
    }
  }
}

esp_err_t event_handler(void *ctx, system_event_t *event) {
  return ESP_OK;
}

void wifi_sniffer_init(void) {
  nvs_flash_init();
  tcpip_adapter_init();
  ESP_ERROR_CHECK( esp_event_loop_init(event_handler, NULL) );
  wifi_init_config_t cfg = WIFI_INIT_CONFIG_DEFAULT();
  ESP_ERROR_CHECK( esp_wifi_init(&cfg) );
  ESP_ERROR_CHECK( esp_wifi_set_country_code("US", false) );
  ESP_ERROR_CHECK( esp_wifi_set_storage(WIFI_STORAGE_RAM) );
  ESP_ERROR_CHECK( esp_wifi_set_mode(WIFI_MODE_NULL) );
  ESP_ERROR_CHECK( esp_wifi_start() );
}

void wifi_sniffer_set_channel(uint8_t channel) {
  esp_wifi_set_channel(channel, WIFI_SECOND_CHAN_NONE);
}

const char * wifi_sniffer_packet_type2str(wifi_promiscuous_pkt_type_t type) {
  switch(type) {
    case WIFI_PKT_MGMT: return "MGMT";
    case WIFI_PKT_DATA: return "DATA";
    case WIFI_PKT_MISC: return "MISC";
    default:  return "";
  }
}

void wifi_sniffer_packet_handler(void* buff, wifi_promiscuous_pkt_type_t type) {

  const wifi_promiscuous_pkt_t *ppkt = (wifi_promiscuous_pkt_t *)buff;
  const wifi_ieee80211_packet_t *ipkt = (wifi_ieee80211_packet_t *)ppkt->payload;
  const wifi_ieee80211_mac_hdr_t *hdr = &ipkt->hdr;

  if (ppkt->rx_ctrl.rssi < MIN_RSSI) {
    return;
  }

  uint64_t timestamp = ppkt->rx_ctrl.timestamp / 1000;  // milliseconds since boot
  // add_mac_to_list(hdr->addr1[0], hdr->addr1[1], hdr->addr1[2], hdr->addr1[3], hdr->addr1[4], hdr->addr1[5], timestamp, ppkt->rx_ctrl.rssi);
  add_mac_to_list(hdr->addr2[0], hdr->addr2[1], hdr->addr2[2], hdr->addr2[3], hdr->addr2[4], hdr->addr2[5], timestamp, ppkt->rx_ctrl.rssi);
  add_mac_to_list(hdr->addr3[0], hdr->addr3[1], hdr->addr3[2], hdr->addr3[3], hdr->addr3[4], hdr->addr3[5], timestamp, ppkt->rx_ctrl.rssi);

  // printf("PACKET TYPE=%s, CHAN=%02d, RSSI=%02d,"
  //   " ADDR1=%02x:%02x:%02x:%02x:%02x:%02x,"
  //   " ADDR2=%02x:%02x:%02x:%02x:%02x:%02x,"
  //   " ADDR3=%02x:%02x:%02x:%02x:%02x:%02x\n",
  //   wifi_sniffer_packet_type2str(type),
  //   ppkt->rx_ctrl.channel,
  //   ppkt->rx_ctrl.rssi,
  //   /* ADDR1 */
  //   hdr->addr1[0],hdr->addr1[1],hdr->addr1[2],
  //   hdr->addr1[3],hdr->addr1[4],hdr->addr1[5],
  //   /* ADDR2 */
  //   hdr->addr2[0],hdr->addr2[1],hdr->addr2[2],
  //   hdr->addr2[3],hdr->addr2[4],hdr->addr2[5],
  //   /* ADDR3 */
  //   hdr->addr3[0],hdr->addr3[1],hdr->addr3[2],
  //   hdr->addr3[3],hdr->addr3[4],hdr->addr3[5]
  // );
}

void setup() {
  Serial.begin(115200);
  batteryGaugeInit();
  WiFi.mode(WIFI_STA);
  pinMode(LED_GPIO_PIN, OUTPUT);
  wifi_sniffer_init();
  delay(100);
  while (!connectWiFi()) {
    delay(100);
  }
  delay(100);
  pingTest();
  delay(100);
  WiFi.disconnect();
  digitalWrite(LED_GPIO_PIN, HIGH);
  esp_wifi_set_promiscuous(true);
  esp_wifi_set_promiscuous_rx_cb(&wifi_sniffer_packet_handler);
  wifi_sniffer_set_channel(channel);
  last_transmission_to_aws = esp_timer_get_time() / 1000; // milliseconds since boot
}

void loop() {
  vTaskDelay(WIFI_CHANNEL_SWITCH_INTERVAL / portTICK_PERIOD_MS);
  remove_departed_macs();
  print_seen_macs();
  int connectCounter = 4;
  bool connectedThisLoop = false;
  // Transmit to AWS IoT every minute
  if (esp_timer_get_time() / 1000 - last_transmission_to_aws >= 60000) {
    esp_wifi_set_promiscuous(false);
    while(connectCounter-- && !connectedThisLoop) {
      if (connectWiFi()) {
        publishMessage();
        connectedThisLoop = true;
      }
      else {
        delay(100);
      }
    }
    esp_wifi_set_promiscuous(true);
    last_transmission_to_aws = esp_timer_get_time() / 1000;
  }
}

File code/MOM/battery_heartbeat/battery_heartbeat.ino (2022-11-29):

#include "secrets.h"
#include "WiFi.h"

#include <ArduinoJson.h>
#include <MQTTClient.h>
#include <SparkFun_MAX1704x_Fuel_Gauge_Arduino_Library.h>
#include <WiFiClientSecure.h>

#define AWS_IOT_PUBLISH_TOPIC       "esp32/pub"
#define LED_GPIO_PIN                13

uint64_t last_transmission_to_aws, sequence, blink_timer;
SFE_MAX1704X lipo;
WiFiClientSecure net = WiFiClientSecure();
MQTTClient client = MQTTClient(256);

bool connectWiFi() {
  WiFi.begin(WIFI_SSID, WIFI_PASSWORD);
  printf("Connecting to Wi-Fi.");
  uint64_t connect_time_start = esp_timer_get_time() / 1000000; // Seconds since boot
  while (WiFi.status() != WL_CONNECTED) {
    delay(500);
    printf(".");
    // Enforce 5-second timeout
    if (esp_timer_get_time() / 1000000 - connect_time_start > 5) {
      printf("Timed out while connecting to %s!\n", WIFI_SSID);
      WiFi.disconnect();
      return false;
    }
  }
  printf(" Connected!\n");
  return true;
}

bool connectAWS() {
  // Set creds to connect to AWS IoT
  net.setCACert(AWS_CERT_CA);
  net.setCertificate(AWS_CERT_CRT);
  net.setPrivateKey(AWS_CERT_PRIVATE);

  client.begin(AWS_IOT_ENDPOINT, 8883, net);
  printf("Connecting to AWS IoT.");

  while (!client.connect(THINGNAME)) {
    printf(".");
    delay(10);
  }

  if (!client.connected()) {
    printf("\nTimed out while connecting to AWS IoT Core!");
    return false;
  }

  printf(" Connected!\n");
  return true;
}

void publishMessage() {
  if (connectAWS()) {
    StaticJsonDocument<200> doc;
    doc["sequence"] = sequence++;
    doc["sender_mac"] = WiFi.macAddress();
    doc["voltage"] = lipo.getVoltage();
    char jsonBuffer[512];
    serializeJson(doc, jsonBuffer); // print to client

    client.publish(AWS_IOT_PUBLISH_TOPIC, jsonBuffer);
    client.disconnect();
  }
}

void setup() {
  Serial.begin(115200);
  WiFi.mode(WIFI_STA);
  connectWiFi();
  pinMode(LED_GPIO_PIN, OUTPUT);
  Wire.begin(3, 4);
  lipo.begin();
  lipo.quickStart();
  sequence = 0;
  publishMessage();
  last_transmission_to_aws = esp_timer_get_time() / 1000;
  blink_timer = last_transmission_to_aws;
}

void loop() {
  if (esp_timer_get_time() / 1000 - blink_timer >= 1000) {
    if (digitalRead(LED_GPIO_PIN) == HIGH) {
      digitalWrite(LED_GPIO_PIN, LOW);
    }
    else {
      digitalWrite(LED_GPIO_PIN, HIGH);
    }
    blink_timer = esp_timer_get_time() / 1000;
    printf("Battery voltage: %f\n", lipo.getVoltage());
  }
  // if (esp_timer_get_time() / 1000 - last_transmission_to_aws >= 60000) {
  //   publishMessage();
  //   last_transmission_to_aws = esp_timer_get_time() / 1000;
  // }
}

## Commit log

2022-09-25 Notebook additions and First Revision of Schematic
    [MOM.kicad_pcb, MOM.kicad_sch]
2022-09-27 New schematic revision and repo cleanup
    [MOM.kicad_sch]
2022-09-30 Schematic updates
    [MOM.kicad_sch]
2022-10-02 Franklin notebook updates
    [MOM.kicad_sch]
2022-10-04 PCB version alpha
    [MOM.kicad_pcb, MOM.kicad_sch]
2022-10-11 Start POC code based off feather
    [MOM.kicad_pcb]
2022-10-12 More groundwork for the POC
2022-10-25 Added Aruba OUI list
    [MOM.kicad_pcb, oui.csv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]
2022-10-26 OUI and wifi_scanner code
    [mac-vendors-export-2022-10-25.csv, oui.csv]
2022-11-02 Scanner can remember MACs it has seen
    [MOM.kicad_pcb]
2022-11-08 updated front end-added battery percentage + more
2022-11-14 added 'next room' button
2022-11-14 added implementation for multiple tabs/rooms with a click of a button, added front end prettifications, cleaned up deprecated code and comments, and added more backend functionality. Need to fix relo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
2022-11-16 Backend readaptation and fixed MC not scanning after first message to AWS
    [MOM_prod.ino]
